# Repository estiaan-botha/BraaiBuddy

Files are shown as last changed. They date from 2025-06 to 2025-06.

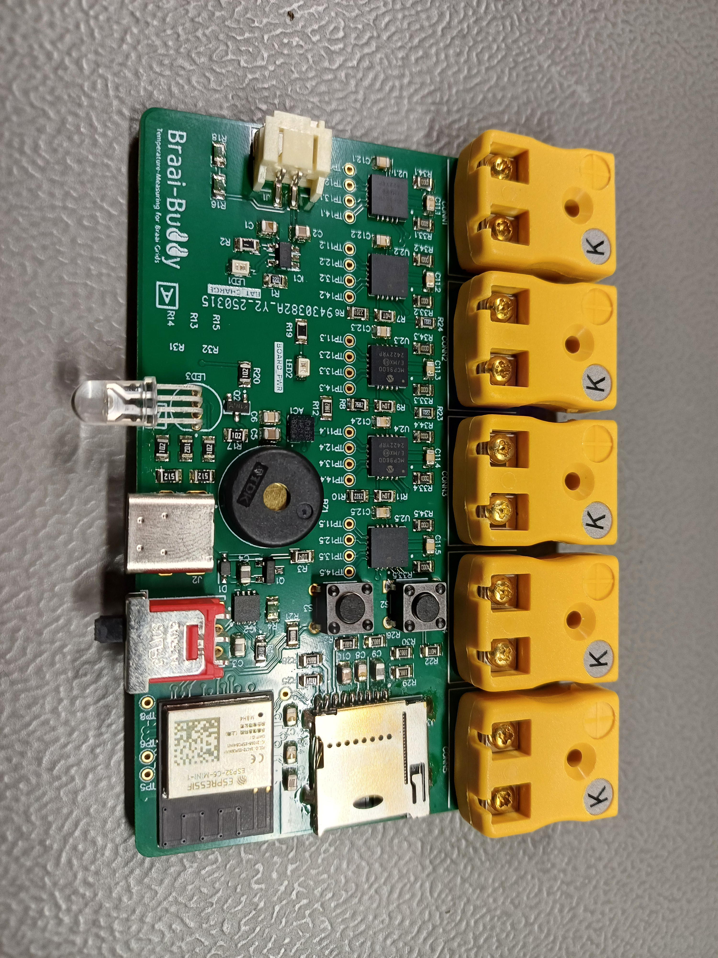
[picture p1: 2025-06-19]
Pictures/real_pcb_photo_2.jpg

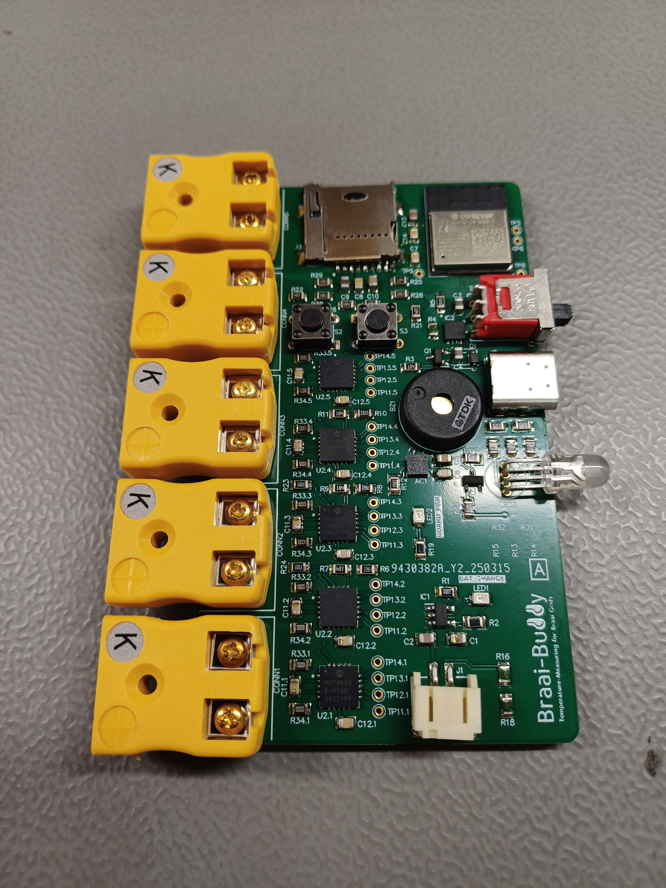
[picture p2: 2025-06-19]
Pictures/real_pcb_photo.jpg

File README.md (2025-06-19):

# BraaiBuddy
BraaiBuddy: Smart Monitoring and Notification System for use in a braai cooking environment.

This repository is for the personal continuation of my final year E&E Engineering project, in which I designed and built a smart device that monitors the internal temperatures of meat and the surface-level cooking temperatures while braaiing. The system can connect with a smart device where real-time temperature information is displayed, and preset selections can be made for the type of meat and the desired level of doneness.

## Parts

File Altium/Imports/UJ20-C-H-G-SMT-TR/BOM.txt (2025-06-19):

3DX_Same_Sky_Supplier: Same Sky
3DX_Same_Sky_Description: Type C, USB 2.0, 480 Mbps, 20 Vdc, 5 A, Right Angle, Gold Flash, Surface Mount, Black Insulator, USB Receptacle
3DX_Same_Sky_Model Number: UJ20-C-H-G-SMT-TR

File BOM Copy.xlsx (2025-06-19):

LibRef | Designator | Quantity | Manufacturer_Part_Number
IC ACC MEMS 3-AXIS 11uA SMD | AC1 | 1 | LIS3DHTR
INDICATOR BUZZER PIEZO PS1240P02CT3 | BZ1 | 1 | PS1240P02CT3
CAP CER 10uF 0805 SMD | C1, C2, C5, C10, C13 | 5 | CL21A106KOQNNNE
CAP CER 2u2F 0805 SMD | C3, C4, C9 | 3 | LMK212BJ225MG-T
CAP CER 100nF 0805 SMD | C6, C7, C8, C11.1, C11.2, C11.3, C11.4, C11.5, C12.1, C12.2, C12.3, C12.4, C12.5, C14 | 14 | 08055C104KAZ2A
CONN AM-K-PCB XE-1139-001 | CONN1, CONN2, CONN3, CONN4, CONN5 | 5 | XE-1139-001
DIODE SCHOTTKY 1A 23V 620mV SMD | D1 | 1 | BAT20JFILM
IC BATT CHG MGNT Li-Po 4V2 REG SMD | IC1 | 1 | MCP73831T-2ACI/OT
IC LDO 1A 5V5 ADJ SMD SON-8 | IC2 | 1 | TPS78501QWDRBRQ1
I/O JST-PH 2-PIN SMT | J1 | 1 | 1769
CONN USB-C 2.0 16 CONTACT 5A 42V SMD | J2 | 1 | UJ20-C-H-G-MSMT-2-P16-TR
SD CARD SOCKET SMD MEM2075-00-140-01-A | J3 | 1 | MEM2075-00-140-01-A
LED YELLOW 0805 SMD | LED1, LED2 | 2 | LY M676-Q2S1-26-Z
LED RGB THP SRAIGHT-LEG | LED3 | 1 | 521-8559F
MOSFET P-CH ENH FET -20V 52mOh -5A SMD | Q1 | 1 | DMG2305UX-7
BJT NPN 3904 SMD SOT-23 | Q2 | 1 | MMBT3904
RES 2.2K 0805 SMD | R1, R23, R24 | 3 | ERJ-PB6B2201V
RES 4.7K 0805 SMD | R2, R19 | 2 | CRCW08054K70FKEA
RES 100K 0805 SMD | R3, R7, R9, R11, R21, R22, R25 | 7 | CRCW0805100KJNECC
RES 200K 0805 SMD | R4, R16, R18 | 3 | SG73P2ATTD2003F
RES 357K 0805 SMD | R5 | 1 | ERJ-6ENF3573V
RES 220K 0805 SMD | R6 | 1 | CR0805-FX-2203ELF
RES 76.8K 0805 SMD | R8 | 1 | RC0805FR-0776K8L
RES 23.2K 0805 SMD | R10 | 1 | RC0805FR-0723K2L
RES 10K 0805 SMD | R12, R26, R27, R28, R29, R30 | 6 | CR0805-FX-1002ELF
RES 1K 0805 SMD | R13, R14, R15, R17, R20 | 5 | RC0805JR-071KL
RES 5.1K 0805 SMD | R31, R32 | 2 | RC0805JR-075K1L
RES 100 0805 SMD | R33.1, R33.2, R33.3, R33.4, R33.5, R34.1, R34.2, R34.3, R34.4, R34.5 | 10 | 1623096-1
SWITCH SPDT 3A 120V | S1 | 1 | 500ASSP1M6QE
BUTT PUSH N/O SPST THP 50mA | S2, S3 | 2 | TS02-66-43-BK-100-LCR-D
ESP32-C6-MINI-1 | U1 | 1 | ESP32-C6-MINI-1-H8
IC TYPE_K AMP I2Q MCP9600-I/MX SMD | U2.1, U2.2, U2.3, U2.4, U2.5 | 5 | MCP9600-E/MX
 |  | 91

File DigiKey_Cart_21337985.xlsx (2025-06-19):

Index | Quantity | Part Number | Manufacturer Part Number | Description | Customer Reference | Available | Backorder | Unit Price | Extended Price ZAR
1 | 5 | 5425-XE-1384-001-ND | XE-1384-001 | BS MINI TYPE K PLUG BM-K-M |  | 5 | 0 | 74.436 | ZAR372,18
2 | 5 | 1778-COM1706-ND | COM1706 | TYPE-K SS STL THERMOCOUPLE |  | 5 | 0 | 108.38 | ZAR541,90
3 | 2 | 497-10613-1-ND | LIS3DHTR | ACCEL 2-16G I2C/SPI 16LGA |  | 2 | 0 | 27.37 | ZAR54,74
4 | 2 | 445-5229-1-ND | PS1240P02CT3 | BUZZER PIEZO 3V 12.2MM TH |  | 2 | 0 | 11.02 | ZAR22,04
5 | 10 | 587-5919-1-ND | LMK212BJ225MG-T | CAP CER 2.2UF 10V X5R 0805 |  | 10 | 0 | 2.021 | ZAR20,21
6 | 10 | 1276-1096-1-ND | CL21A106KOQNNNE | CAP CER 10UF 16V X5R 0805 |  | 10 | 0 | 0.625 | ZAR6,25
7 | 28 | 478-KGF21BR71H104KTCT-ND | 08055C104KAZ2A | CAP CER 0.1UF 50V X7R 0805 |  | 28 | 0 | 2.921 | ZAR81,79
8 | 5 | 5425-XE-1139-001-ND | XE-1139-001 | ANSI TYPE K PCB SOCKET AM-K-PCB |  | 5 | 0 | 74.436 | ZAR372,18
9 | 5 | 497-3381-1-ND | BAT20JFILM | DIODE SCHOTTKY 23V 1A SOD323 |  | 5 | 0 | 4.96 | ZAR24,80
10 | 3 | MCP73831T-2ACI/OTCT-ND | MCP73831T-2ACI/OT | IC BATT CNTL LI-ION 1CEL SOT23-5 |  | 3 | 0 | 13.96 | ZAR41,88
11 | 3 | 296-TPS78501QWDRBRQ1CT-ND | TPS78501QWDRBRQ1 | IC REG LINEAR POS ADJ 1A 8-SON |  | 3 | 0 | 27.19 | ZAR81,57
12 | 2 | 2073-MEM2075-00-140-01-ACT-ND | MEM2075-00-140-01-A | CONN MICRO SD CARD R/A SMD |  | 2 | 0 | 34.17 | ZAR68,34
13 | 3 | 350-5218559F-ND | 5218559F | LED RGB CLEAR 5MM T/H |  | 3 | 0 | 15.8 | ZAR47,40
14 | 5 | DMG2305UX-7DICT-ND | DMG2305UX-7 | MOSFET P-CH 20V 4.2A SOT23 |  | 5 | 0 | 3.86 | ZAR19,30
15 | 10 | P20630CT-ND | ERJ-PB6B2201V | RES SMD 2.2K OHM 0.1% 1/4W 0805 |  | 10 | 0 | 2.498 | ZAR24,98
16 | 10 | 541-4.70KCCT-ND | CRCW08054K70FKEA | RES SMD 4.7K OHM 1% 1/8W 0805 |  | 10 | 0 | 0.772 | ZAR7,72
17 | 20 | 118-CR0805-JW-104ELFCT-ND | CR0805-JW-104ELF | RES SMD 100K OHM 5% 1/8W 0805 |  | 20 | 0 | 0.423 | ZAR8,46
18 | 10 | 2019-SG73P2ATTD2003FCT-ND | SG73P2ATTD2003F | RES 200K OHM 1% 1/2W 0805 |  | 10 | 0 | 1.176 | ZAR11,76
19 | 10 | P357KCCT-ND | ERJ-6ENF3573V | RES SMD 357K OHM 1% 1/8W 0805 |  | 10 | 0 | 0.974 | ZAR9,74
20 | 10 | CR0805-FX-2203ELFCT-ND | CR0805-FX-2203ELF | RES SMD 220K OHM 1% 1/8W 0805 |  | 10 | 0 | 0.514 | ZAR5,14
21 | 10 | 311-76.8KCRCT-ND | RC0805FR-0776K8L | RES 76.8K OHM 1% 1/8W 0805 |  | 10 | 0 | 0.22 | ZAR2,20
22 | 10 | 311-23.2KCRCT-ND | RC0805FR-0723K2L | RES 23.2K OHM 1% 1/8W 0805 |  | 10 | 0 | 0.202 | ZAR2,02
23 | 20 | CR0805-FX-1002ELFCT-ND | CR0805-FX-1002ELF | RES SMD 10K OHM 1% 1/8W 0805 |  | 20 | 0 | 0.478 | ZAR9,56
24 | 10 | 311-1.0KARCT-ND | RC0805JR-071KL | RES 1K OHM 5% 1/8W 0805 |  | 10 | 0 | 0.22 | ZAR2,20
25 | 20 | A106053CT-ND | CRG0805F100R | RES SMD 100 OHM 1% 1/8W 0805 |  | 20 | 0 | 0.643 | ZAR12,86
26 | 1 | EG2483-ND | 500ASSP1M6QE | SWITCH SLIDE SPDT 3A 120V |  | 1 | 0 | 99.75 | ZAR99,75
27 | 4 | 2223-TS02-66-43-BK-100-LCR-D-ND | TS02-66-43-BK-100-LCR-D | SWITCH TACTILE SPST-NO 0.05A 12V |  | 4 | 0 | 1.84 | ZAR7,36
28 | 6 | MCP9600-E/MX-ND | MCP9600-E/MX | IC THERMOCOUPLE TO I2C 20MQFN |  | 6 | 0 | 161.47 | ZAR968,82
29 | 5 | MMBT3904-FDICT-ND | MMBT3904-7-F | TRANS NPN 40V 0.2A SOT-23-3 |  | 5 | 0 | 2.2 | ZAR11,00
30 | 10 | 311-5.1KARCT-ND | RC0805JR-075K1L | RES 5.1K OHM 5% 1/8W 0805 |  | 10 | 0 | 0.147 | ZAR1,47
31 | 2 | 455-S2B-PH-SM4-TBCT-ND | S2B-PH-SM4-TB | CONN HEADER SMD R/A 2POS 2MM |  | 2 | 0 | 9.37 | ZAR18,74
32 | 4 | 475-LYM676-Q2T1-26-ZCT-ND | LY M676-Q2T1-26-0-20-R18-Z | LED YELLOW CLEAR 2SMD |  | 4 | 0 | 6.43 | ZAR25,72
33 | 4 | 2223-UJ20-C-H-G-SMT-TRCT-ND | UJ20-C-H-G-SMT-TR | TYPE C, USB 2.0, 480 MBPS, 20 VA |  | 4 | 0 | 19.29 | ZAR77,16
34 | 2 | 1965-ESP32-C6-MINI-1-H4CT-ND | ESP32-C6-MINI-1-H4 | RF TXRX MODULE BT PCB TRACE SMD |  | 2 | 0 | 82.85 | ZAR165,70

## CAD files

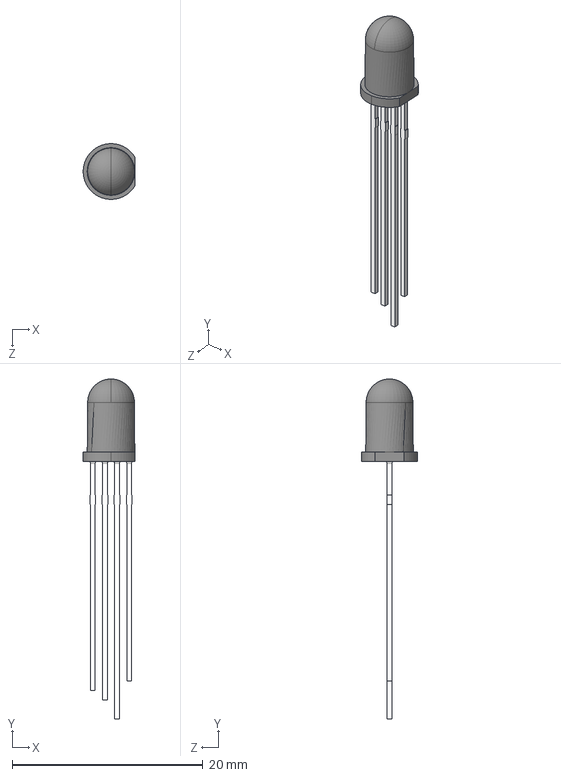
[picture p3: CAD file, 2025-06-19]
Altium/Imports/HV-5RGB25/3D/HV-5RGB25.stp
5.42 x 35.6 x 5.85 mm

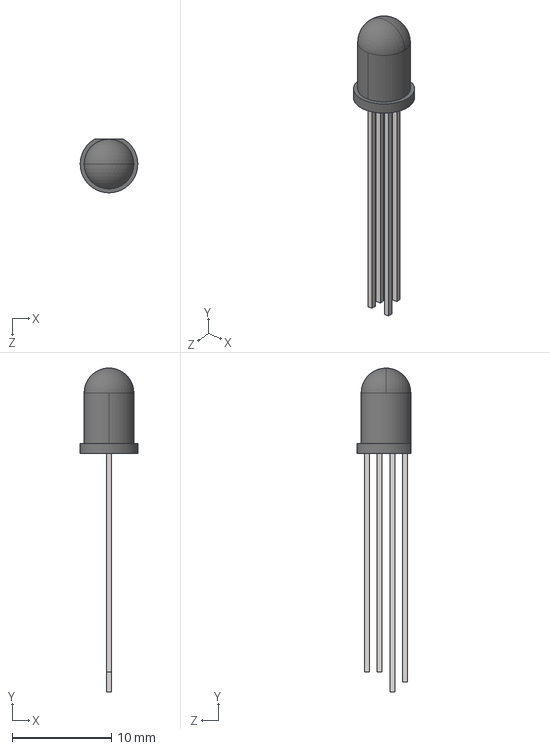
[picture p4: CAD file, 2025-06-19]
Altium/Imports/LIB_521-8559F/521-8559F/3D/521-8559F.stp
5.79 x 32.6 x 5.40 mm

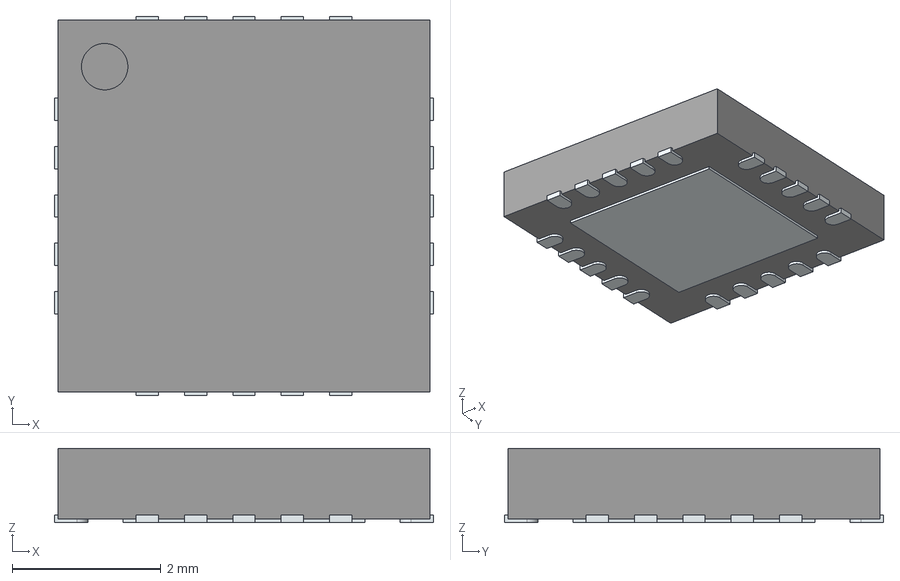
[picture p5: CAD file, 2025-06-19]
Altium/Imports/LIB_MCP9600-E_MX/MCP9600-E_MX/3D/MCP9600-E_MX.stp
5.10 x 5.10 x 1.00 mm
ThermalPin
PinsArrayLR
PinsArrayTB

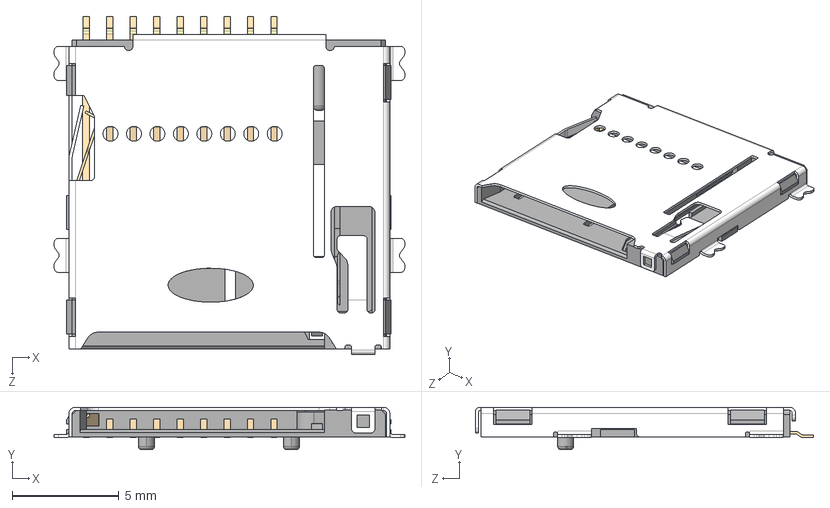
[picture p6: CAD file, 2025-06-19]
Altium/Imports/LIB_MEM2075-00-140-01-A/MEM2075-00-140-01-A/3D/MEM2075-00-140-01-A.stp
16.4 x 1.99 x 15.9 mm
MEM2075-00-140-01-A
MEM2075-00-140-01-A_1
MEM2075-00-140-01-A_2

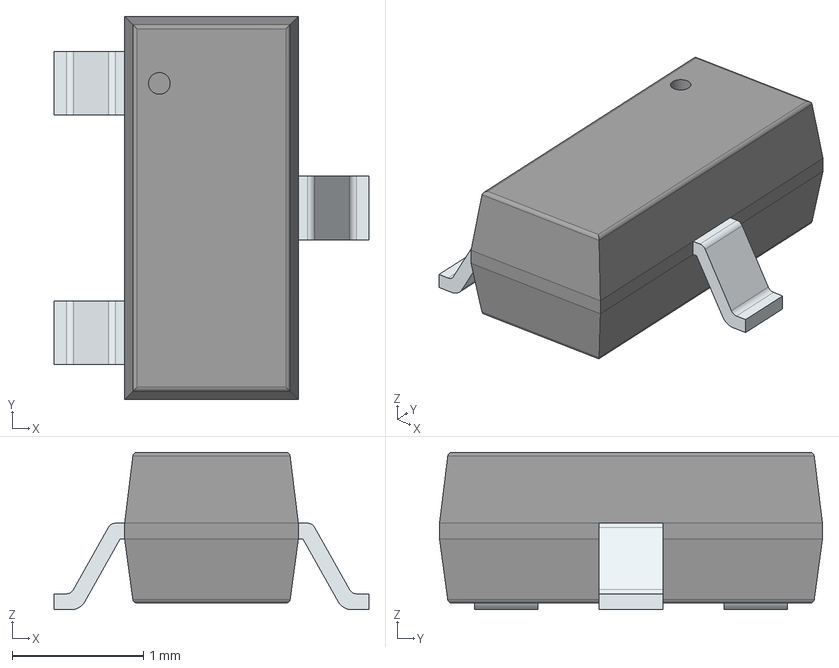
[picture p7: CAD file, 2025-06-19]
Altium/Imports/MMBT3904.stp
2.40 x 2.92 x 1.20 mm
PinsArrayL
FilletPinR

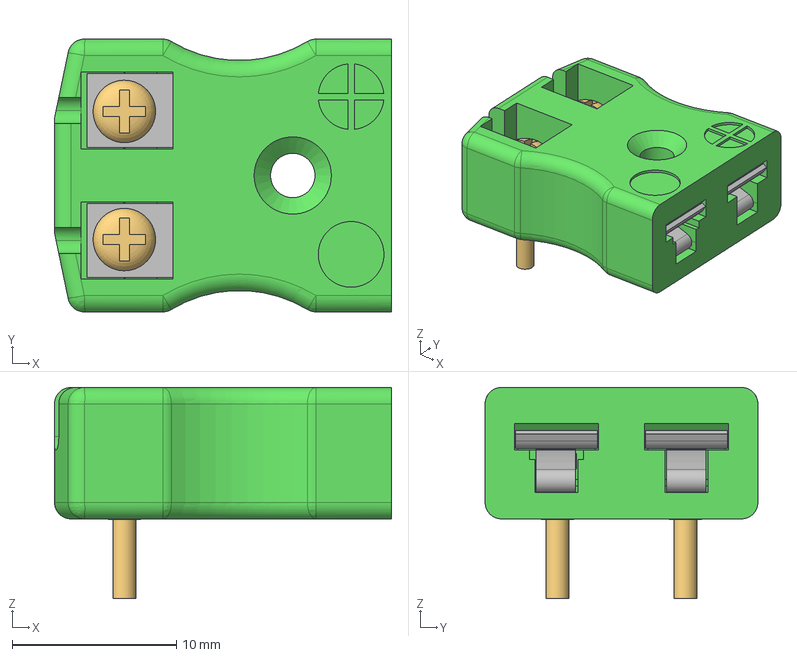
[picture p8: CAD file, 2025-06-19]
Altium/Imports/pcb-socket-for-type-k-thermocouple-1.snapshot.7/IM-K-PCB.step
20.5 x 16.6 x 12.9 mm
BottomBlade x 2
Screw x 2
M2-Écrou x 2
TopBlade x 2

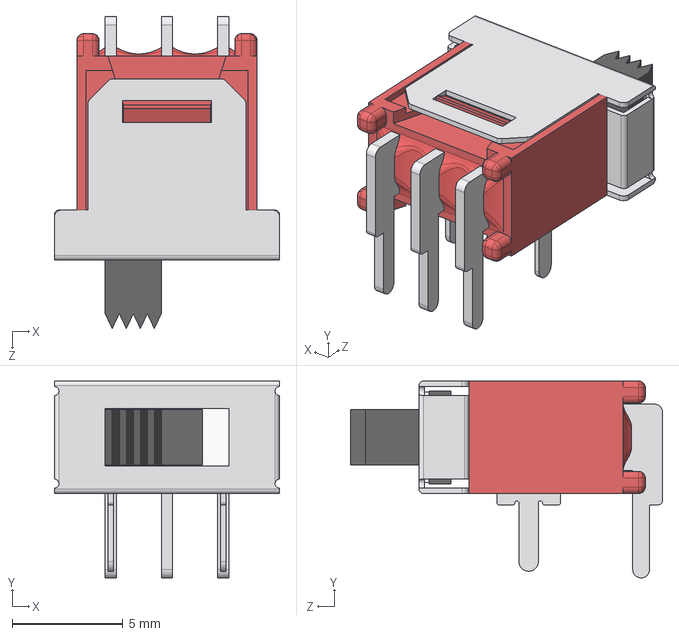
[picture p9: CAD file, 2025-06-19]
Altium/Imports/500ASSP1M6QE.step
10.2 x 8.89 x 14.1 mm

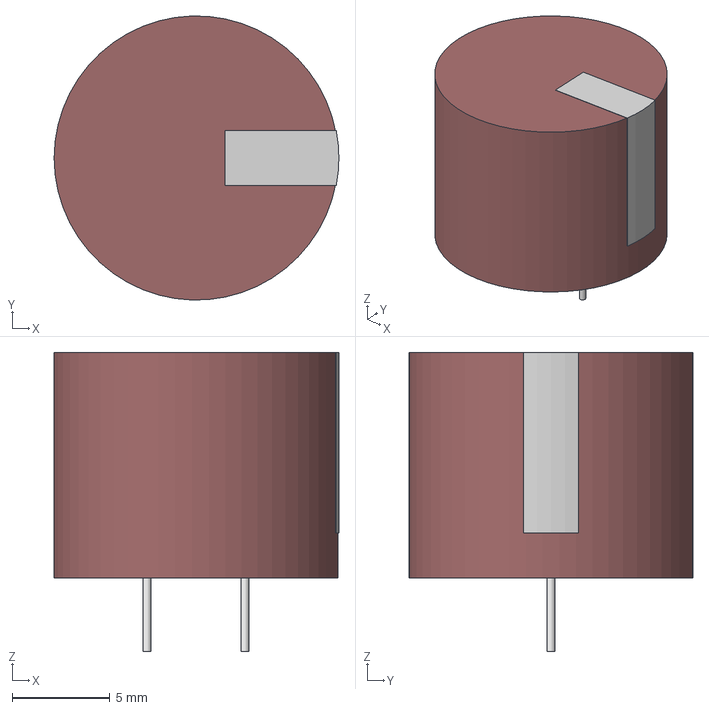
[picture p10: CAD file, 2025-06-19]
Altium/Imports/SMT_PP02CT3_TDK.step
14.5 x 14.5 x 15.3 mm

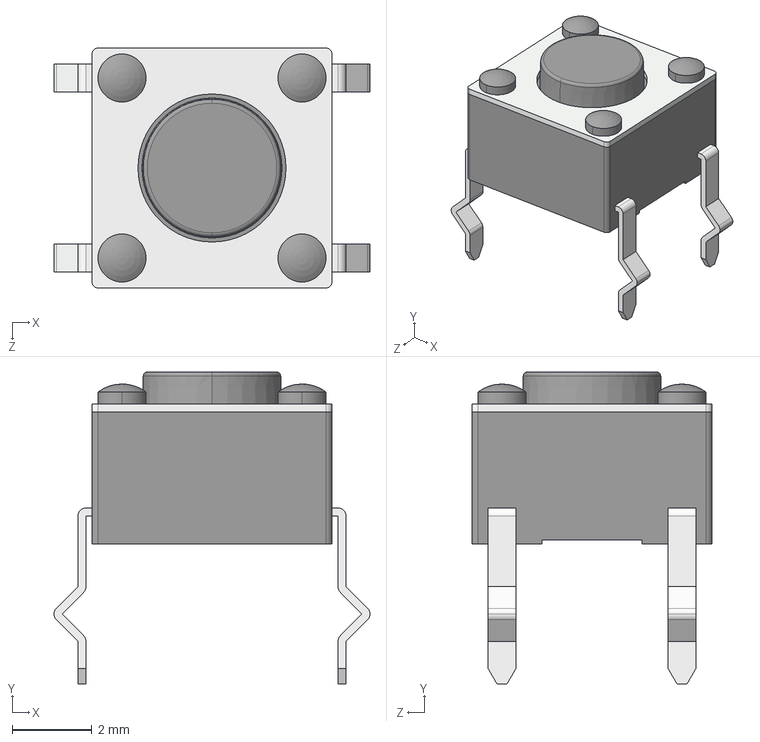
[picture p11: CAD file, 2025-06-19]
Altium/Imports/TS02-66-43-BK-100-LCR-D.step
7.90 x 7.80 x 6.00 mm

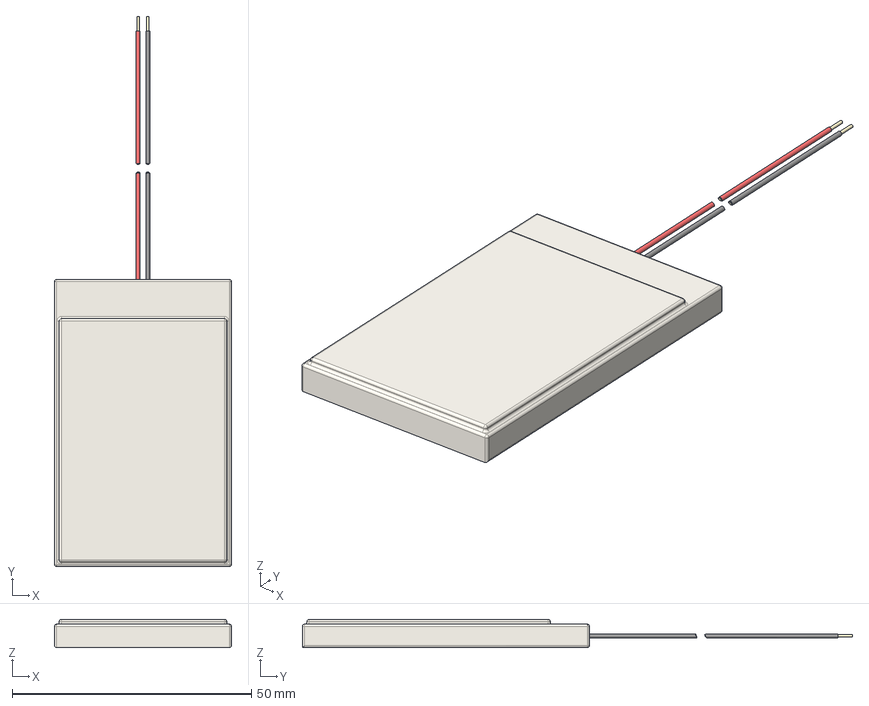
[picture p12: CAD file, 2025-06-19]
Altium/Imports/LIB_ICP543759PMT/ICP543759PMT/3D/ICP543759PMT.stp
37.0 x 115.0 x 5.90 mm

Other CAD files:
Altium/Imports/pcb-socket-for-type-k-thermocouple-1.snapshot.7/AM-K-PCB.step
Altium/Imports/HV-5RGB25/Allegro/hv5rgb25.psm
Altium/Imports/HV-5RGB25/DEHDL/hv_5rgb25/chips/chips.prt
Altium/Imports/LIB_521-8559F/521-8559F/Allegro/5218559f.psm
Altium/Imports/LIB_521-8559F/521-8559F/DEHDL/521_8559f/chips/chips.prt
Altium/Imports/LIB_MCP9600-E_MX/MCP9600-E_MX/Allegro/qfn65p500x500x100-21n-d.psm
Altium/Imports/LIB_MCP9600-E_MX/MCP9600-E_MX/DEHDL/mcp9600_e_mx/chips/chips.prt
Altium/Imports/LIB_MEM2075-00-140-01-A/MEM2075-00-140-01-A/Allegro/mem20750014001a.psm
Altium/Imports/LIB_MEM2075-00-140-01-A/MEM2075-00-140-01-A/DEHDL/mem2075_00_140_01_a/chips/chips.prt
Altium/Imports/UJ20-C-H-G-SMT-TR/Same_Sky_UJ20-C-H-G-SMT-TR.x_t

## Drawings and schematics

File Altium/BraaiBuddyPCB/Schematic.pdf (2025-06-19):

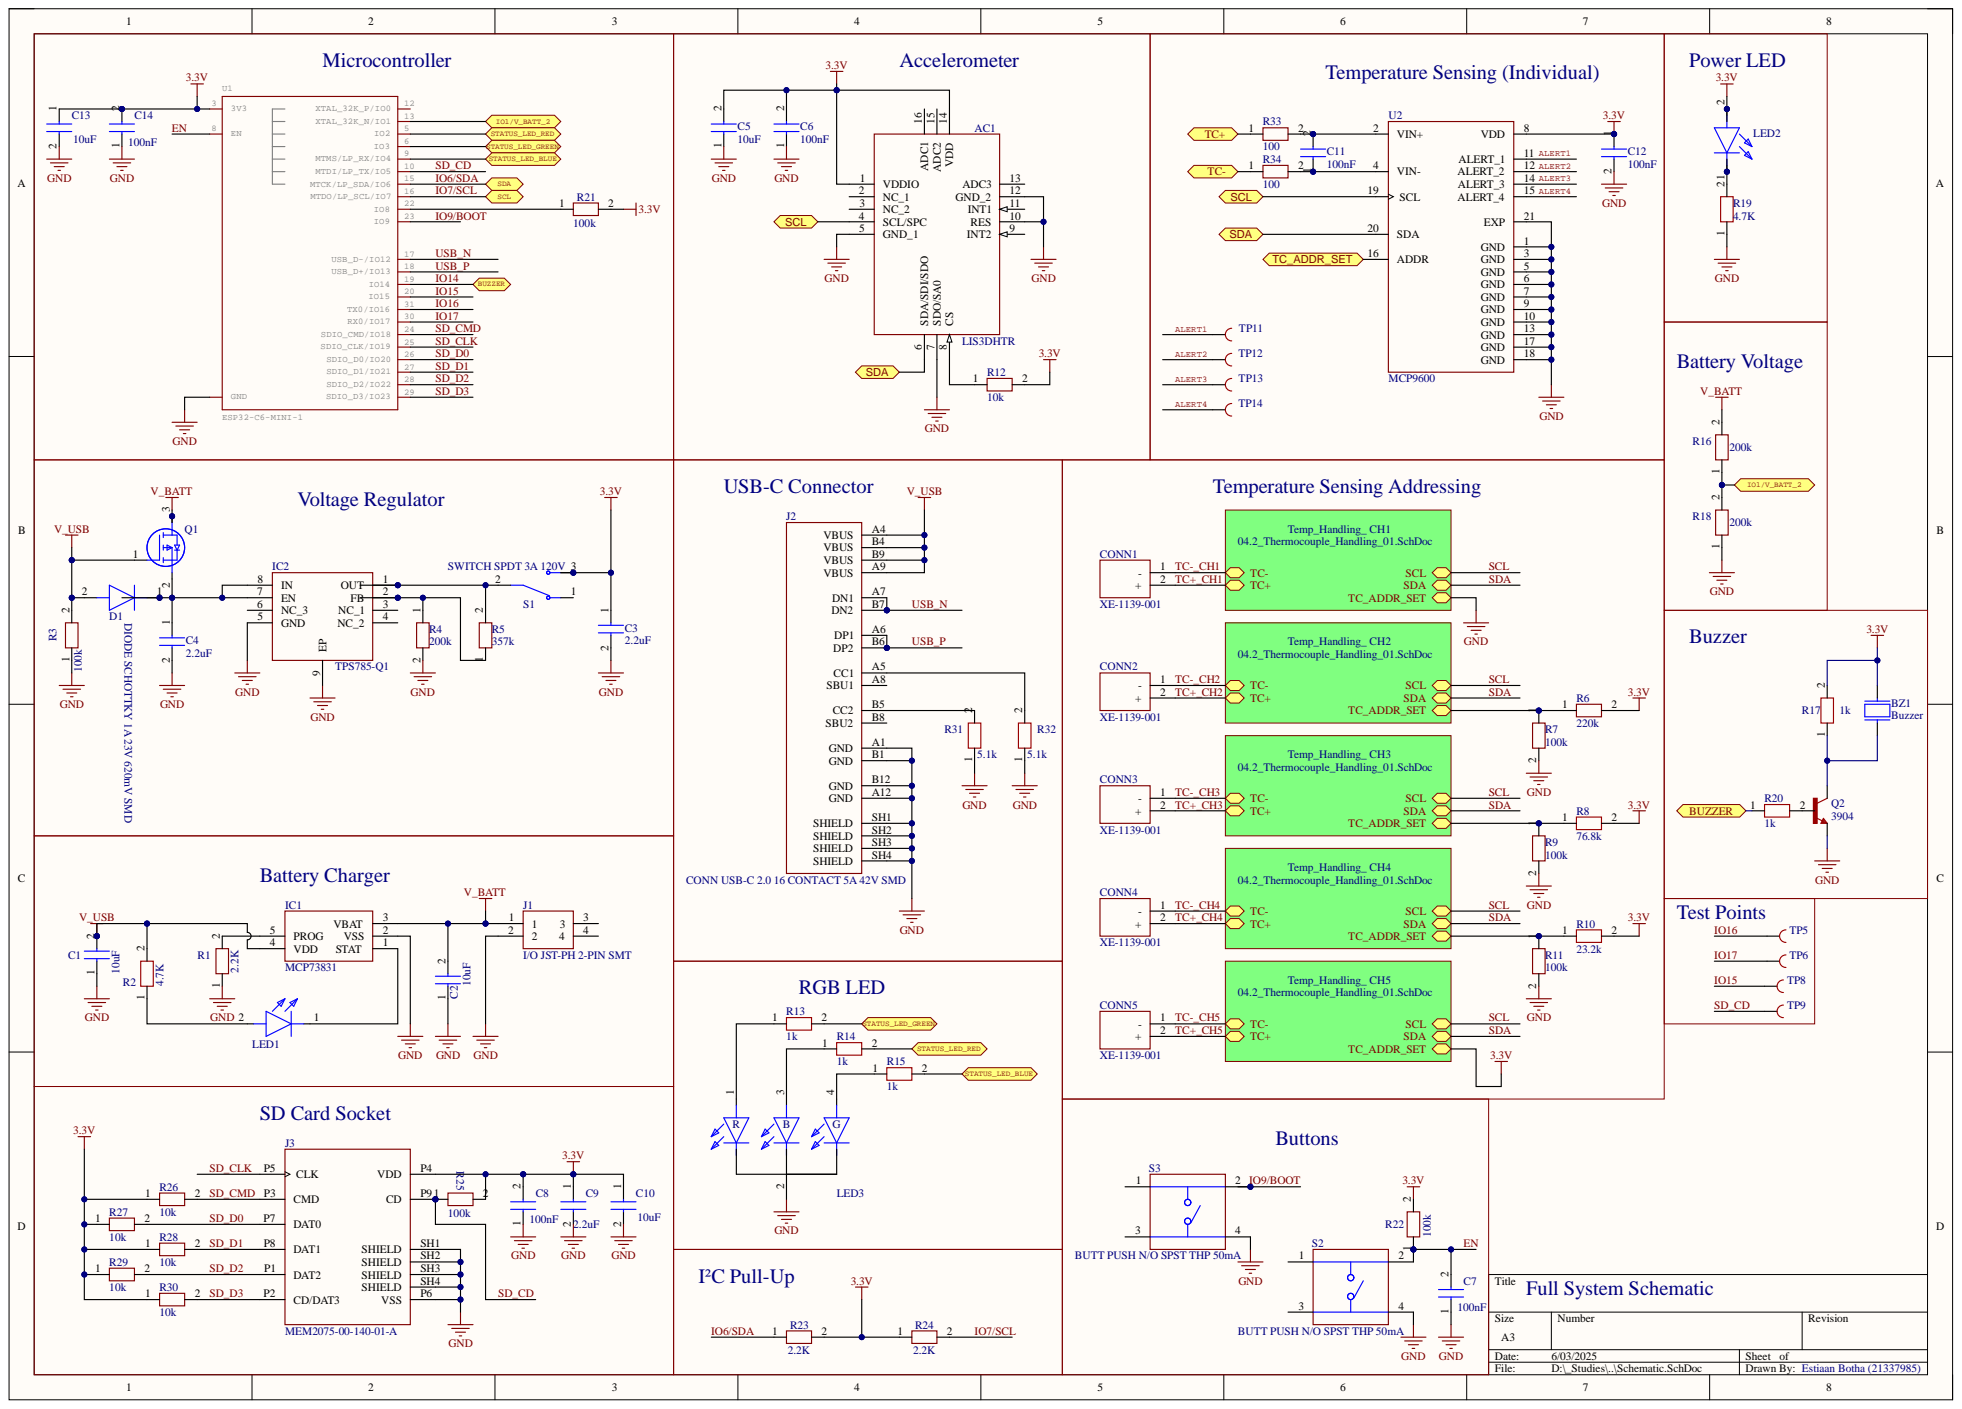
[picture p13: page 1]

CONN USB-C 2.0 16 CONTACT 5A 42V SMD

I/O JST-PH 2-PIN SMT

BUTT PUSH N/O SPST THP 50mA

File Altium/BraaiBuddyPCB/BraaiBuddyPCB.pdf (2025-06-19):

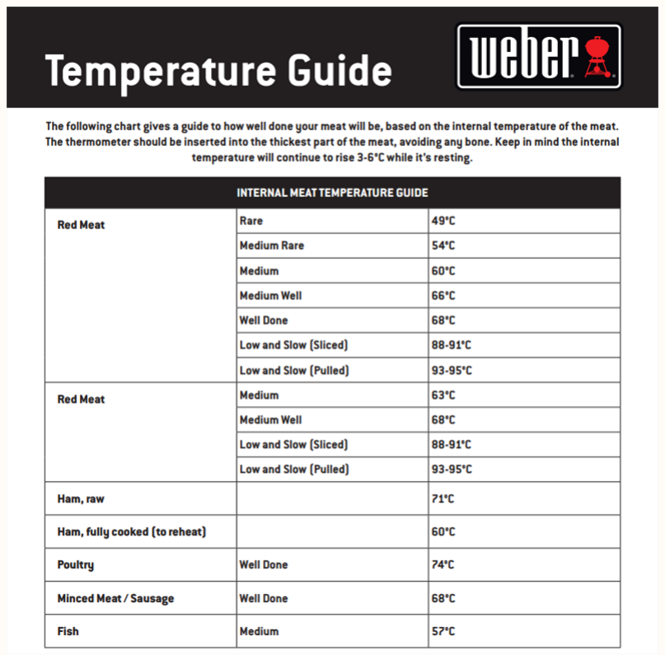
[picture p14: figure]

A | A

+3V6

Power Management

02_Power.SchDoc

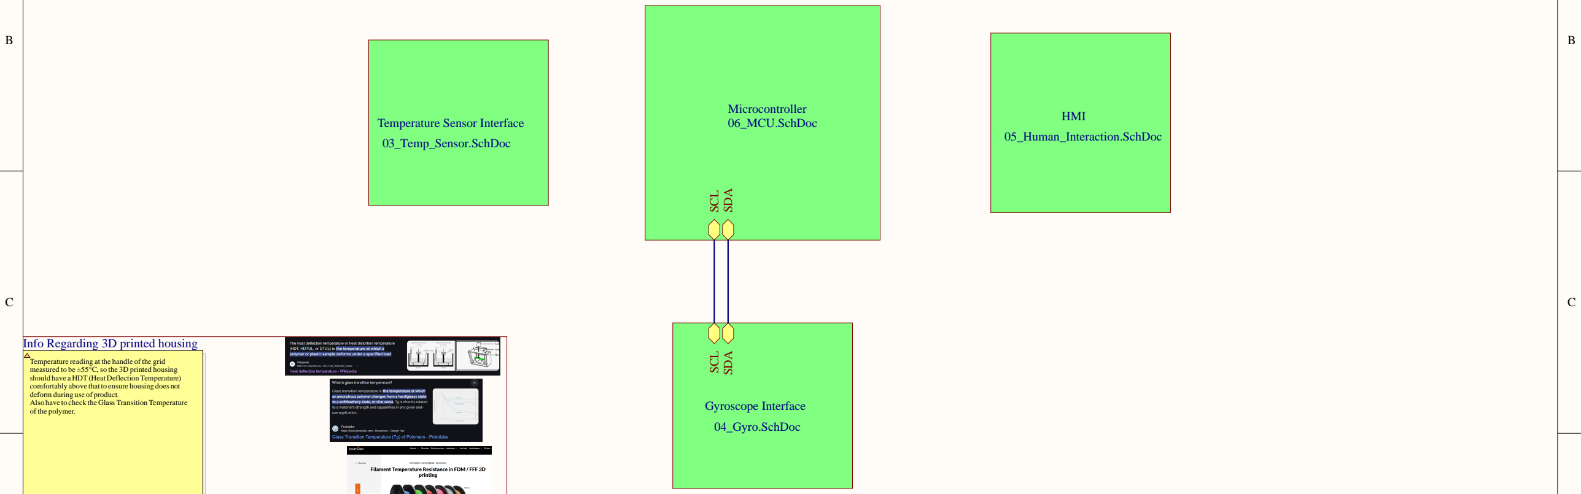
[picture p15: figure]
SCL; SDA Microcontroller; Temperature Sensor Interface; 06_MCU.SchDoc; 03_Temp_Sensor.SchDoc; SDA; Gyroscope Interface; 04_Gyro.SchDoc; HMI; 05_Human_Interaction.SchDoc; Info Regarding 3D printed housing; deform during use of product.; of the polymer.
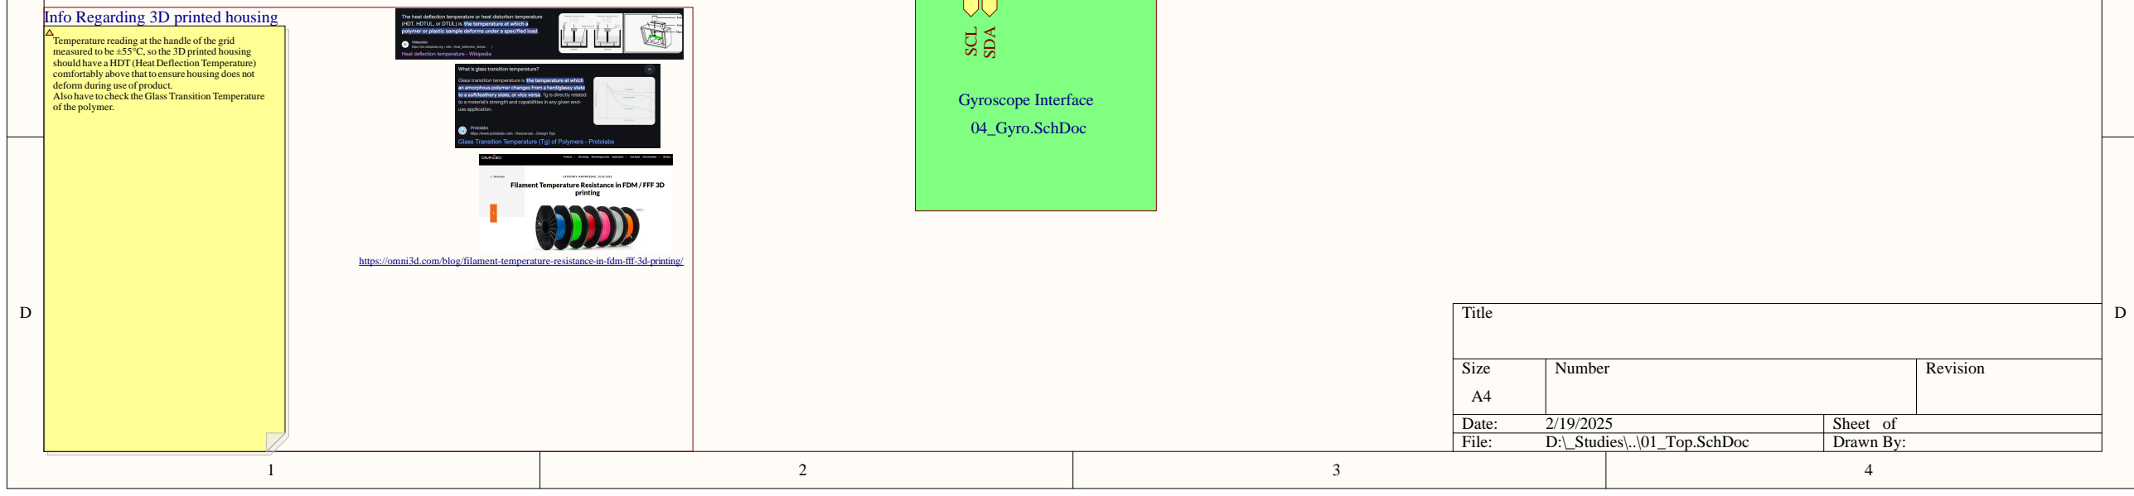
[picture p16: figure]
Title; Size; Number; Revision; Date:; Sheet of; File:; D:\_Studies\..\01_Top.SchDoc; Drawn By:; https://omni3d.com/blog/filament-temperature-resistance-in-fdm-fff-3d-printing/

Temperature reading at the handle of the grid measured to be ±55°C, so the 3D printed housing should have a HDT(Heat Deflection Temperature) comfortably above that to ensure housing does not

Also have to check the Glass Transition Temperature

Product Specifications:
Battery Life: 2 hours

Temperature sensing range (max): 400°C (or roughly 350°C)

Module operating temperature range: roughly 60°C ambient on outside of module. With heat insulation in place, hopefully reduce ambient temperature to a max of 40°C (possibly lower)

Sensing accuracy (max): ±2°C (since meat has a 5°C range between doneness levels)

Interaction: rocker power switch, LEDs to indicate when grill needs to be turned, connect to mobile through WiFi and display GUI, run HTML web app with arelevant information and selection of presets

Gyro: to sense when the grid has been flipped

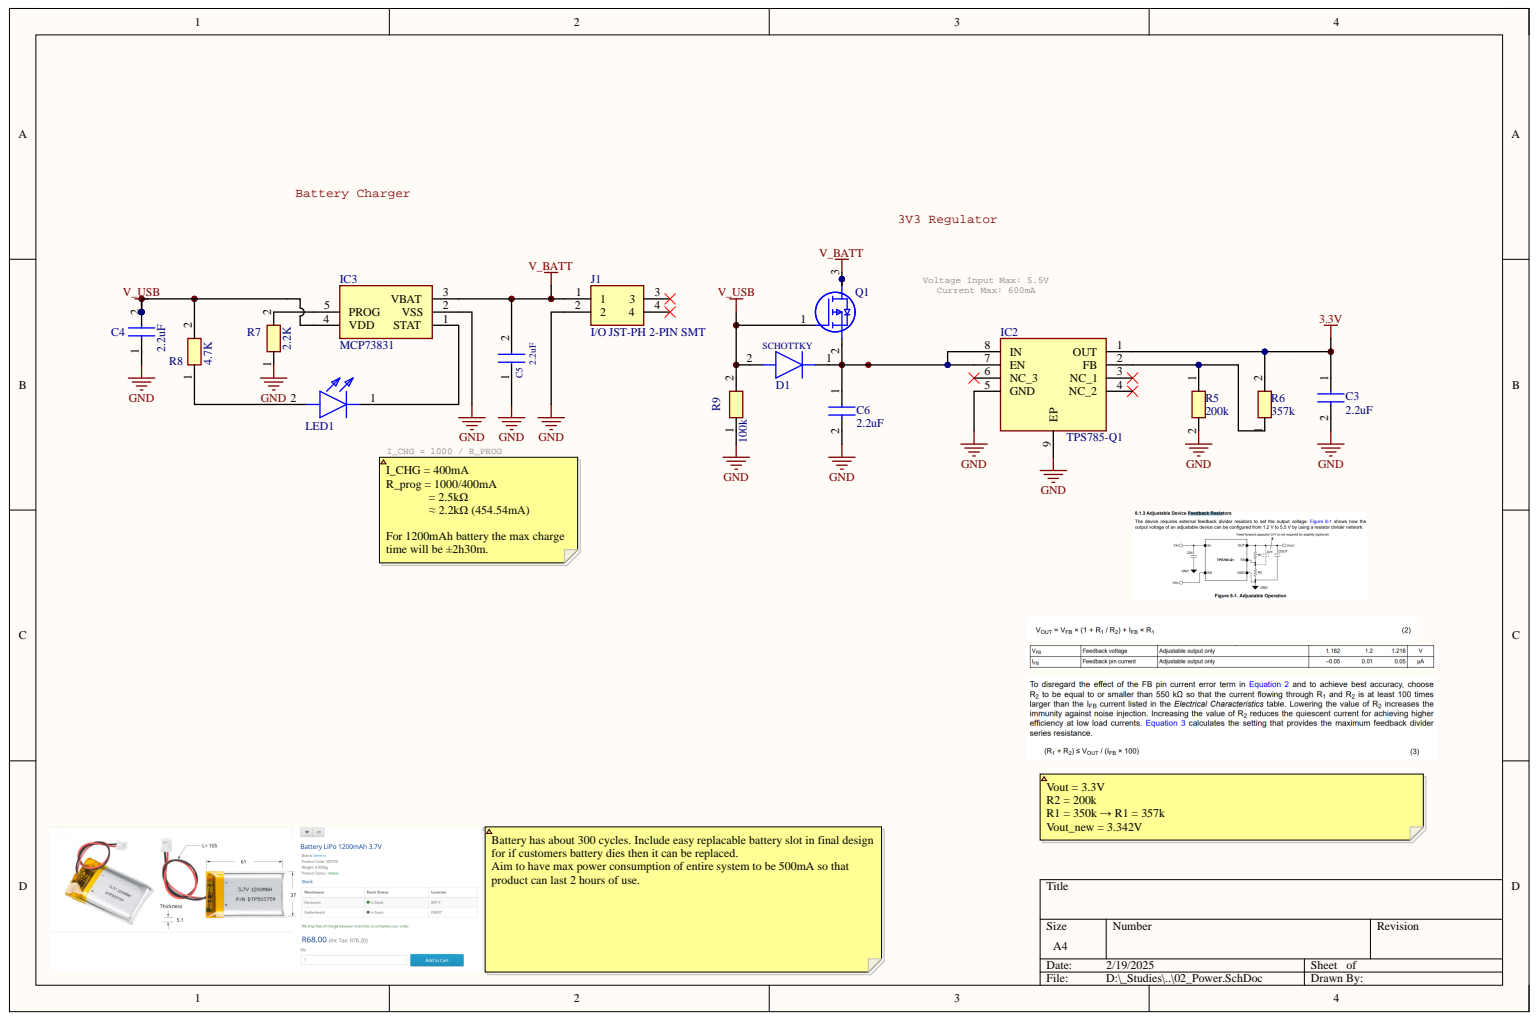
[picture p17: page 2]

For 1200mAh battery the max charge
time will be

Battery has about 300 cycles. Include easy replacable battery slot in final design
for if customers battery dies then it can be replaced.
Aim to have max power consumption of entire system to be 500mA so that
product can last 2 hours of use.

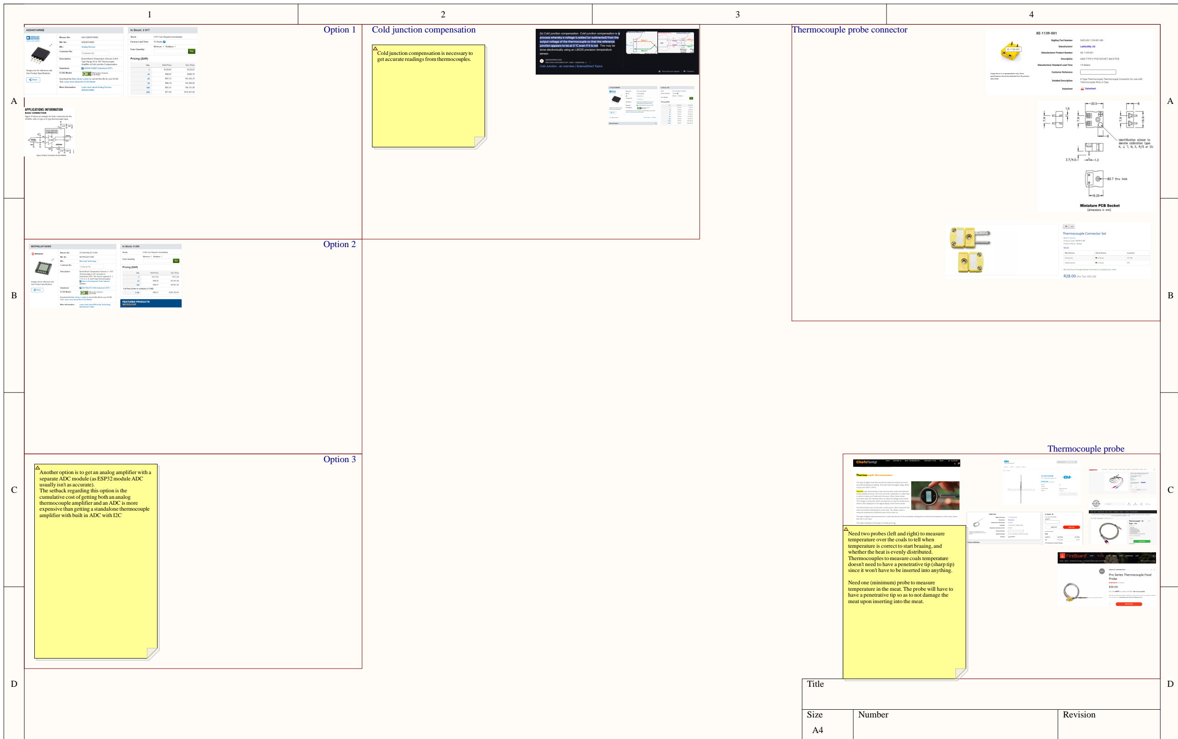
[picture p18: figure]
Title; Size; Number; Revision; Option 1; Option 2; Thermocouple probe connector; Thermocouple probe; Cold junction compensation; Option 3; temperature over the coals to tell when; whether the heat is evenly distributed. Thermocouples to measure coals temperature; Need one (minimum) probe to measure; meat upon inserting into the meat.; get accurate readings from thermocouples.; usually isn't as accurate).; amplifier with built in ADC with I2C
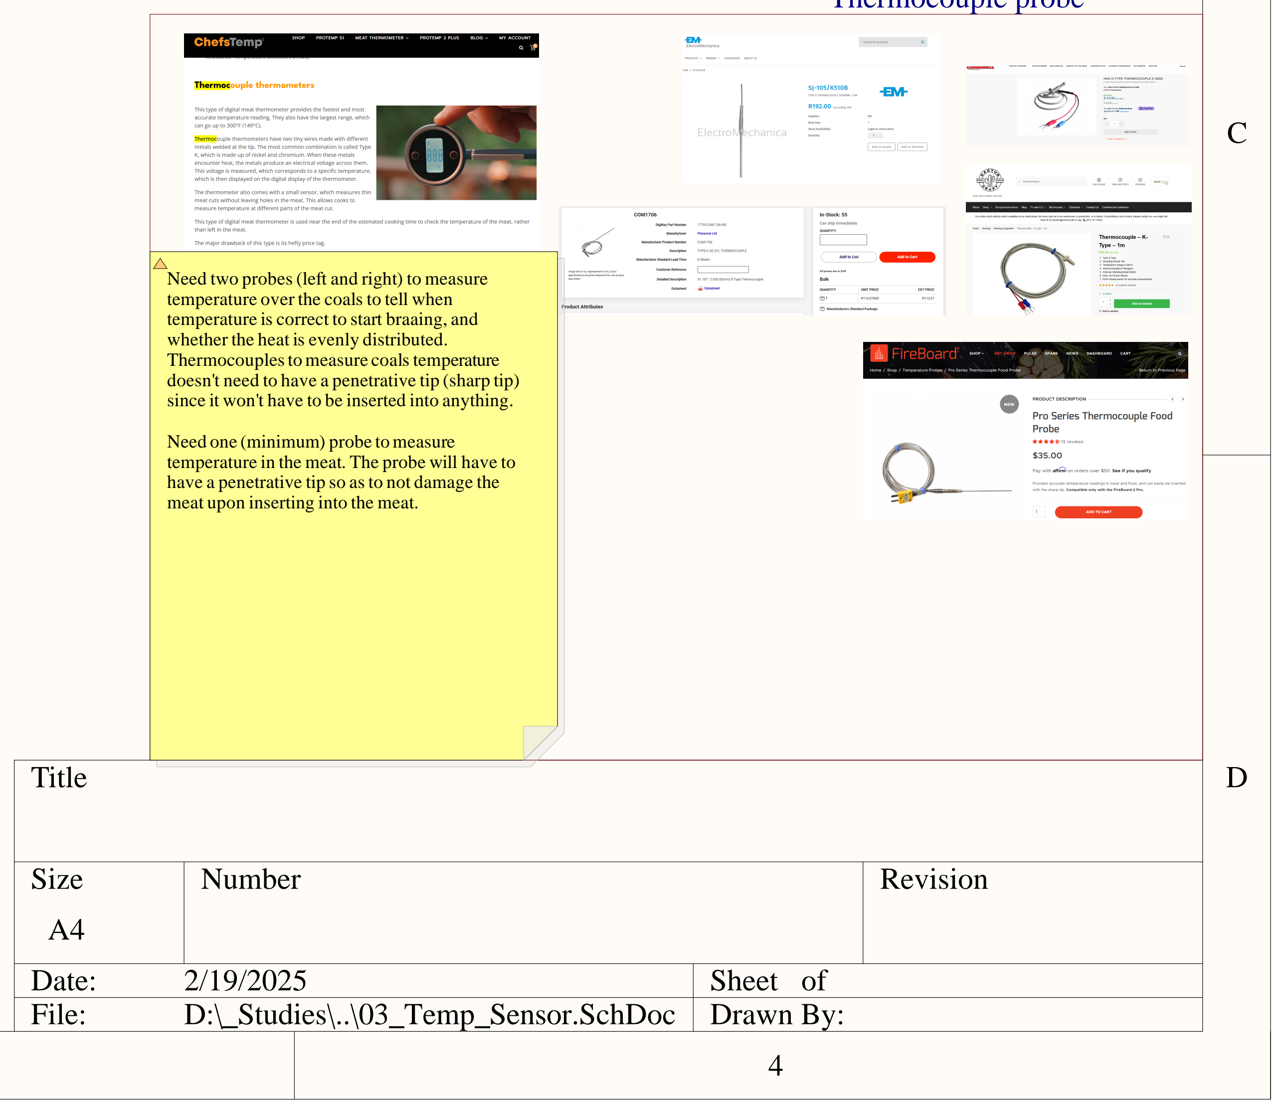
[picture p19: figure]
File:; D:\_Studies\..\03_Temp_Sensor.SchDoc; Drawn By:

Need two probes (left and right) to measure

temperature is correct to start braaing, and

doesn't need to have a penetrative tip (sharp tip) since it won't have to be inserted into anything.

temperature in the meat. The probe will have to have a penetrative tip so as to not damage the

Cold junction compensation is necessary to

Another option is to get an analog amplifier with a separate ADC module (as ESP32 module ADC

The setback regarding this option is the cumulative cost of getting both an analog thermocouple amplifier and an ADC is more expensive than getting a standalone thermocouple

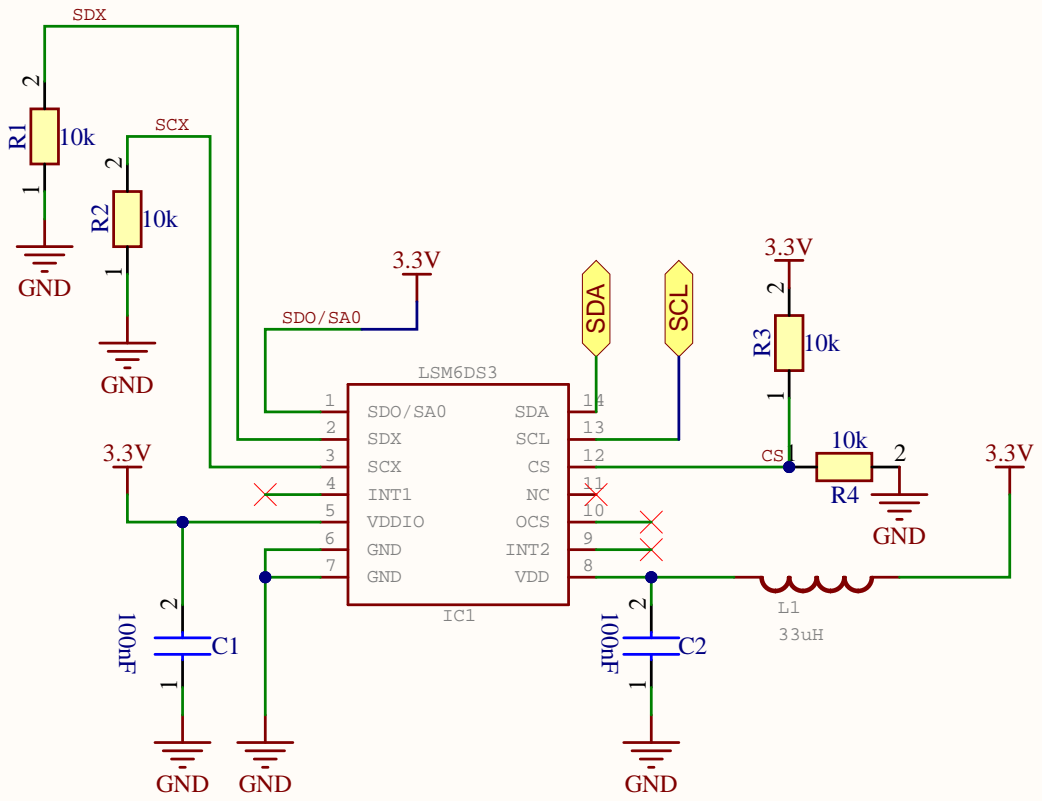
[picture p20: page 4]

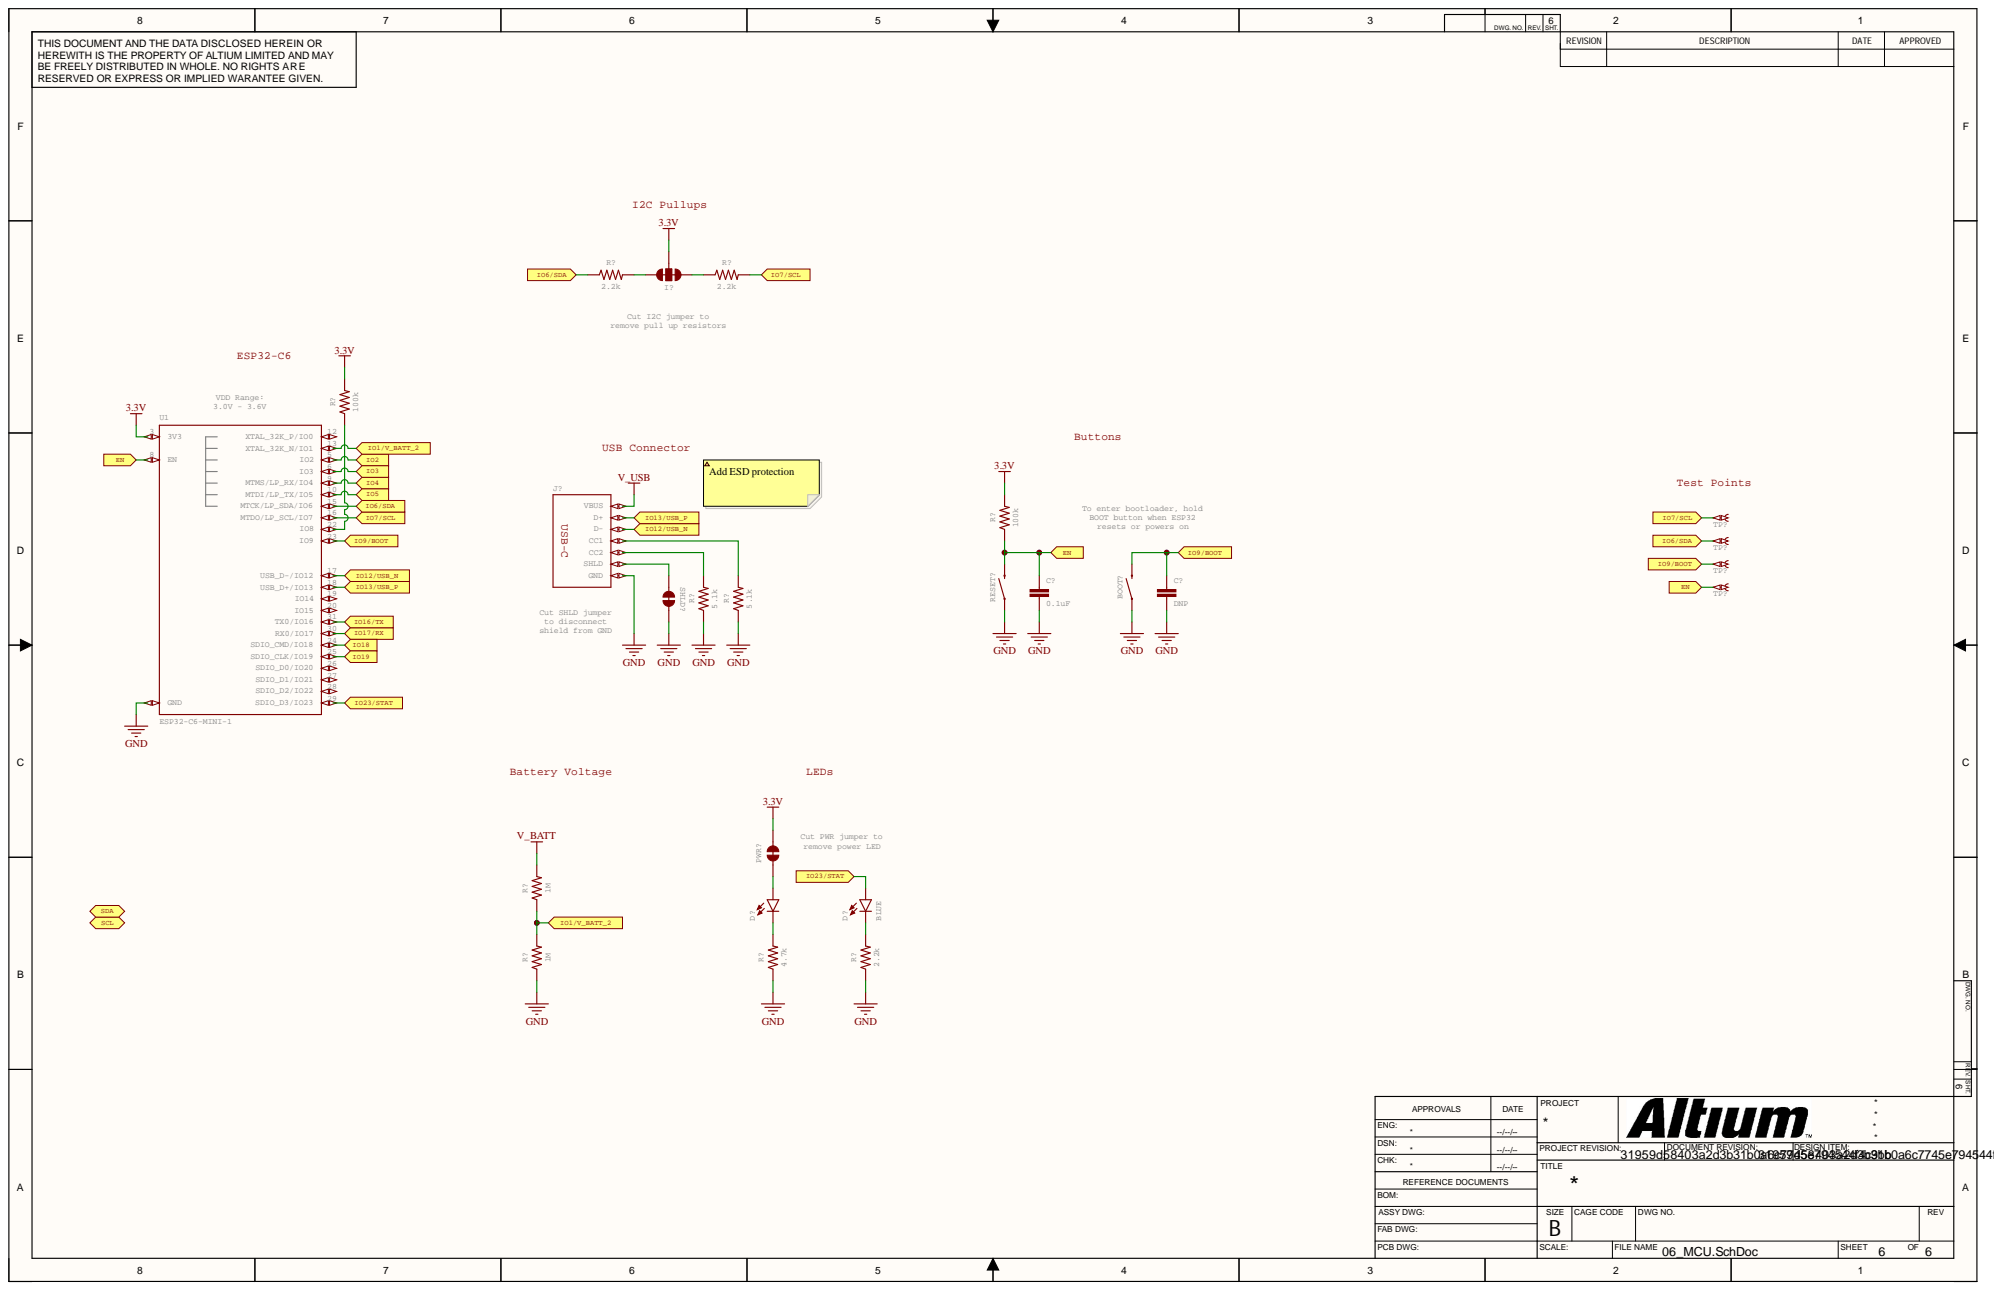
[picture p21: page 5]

THIS DOCUMENT AND THE DA TA DISCLOSED HEREIN OR HEREWITH IS THE PROPERTY OF ALTIUM LIMITED AND MA Y BE FREEL Y DISTRIBUTED IN WHOLE. NO RIGHTS ARE RESERVED OR EXPRESS OR IMPLIED WARANTEE GIVEN. | P u l 3 . 3 V | RE VISIO N | DE SCRIPTIO N | DATE | A P PROV E D

DWG. NO. | RE V. | SHT | .

REV. SHT. DWG. NO.

A P PRO VALS | DATE | PRO J ECT * | ****

ENG : | --/--/--
** DSN: | --/--/--

PRO J ECT RE VISION: 3 1 9 5 9 d | DOCUMENT RE VISION: 5 8 4 0 3 a 2 d 3 b 3 1 b 03a169c57 97 | DE SIGN ITEM: d4 5 e8 74 90435a424df34bc39 1b b 0 a 6 c 7 7 4 5 e | 7

CHK : * | --/--/--

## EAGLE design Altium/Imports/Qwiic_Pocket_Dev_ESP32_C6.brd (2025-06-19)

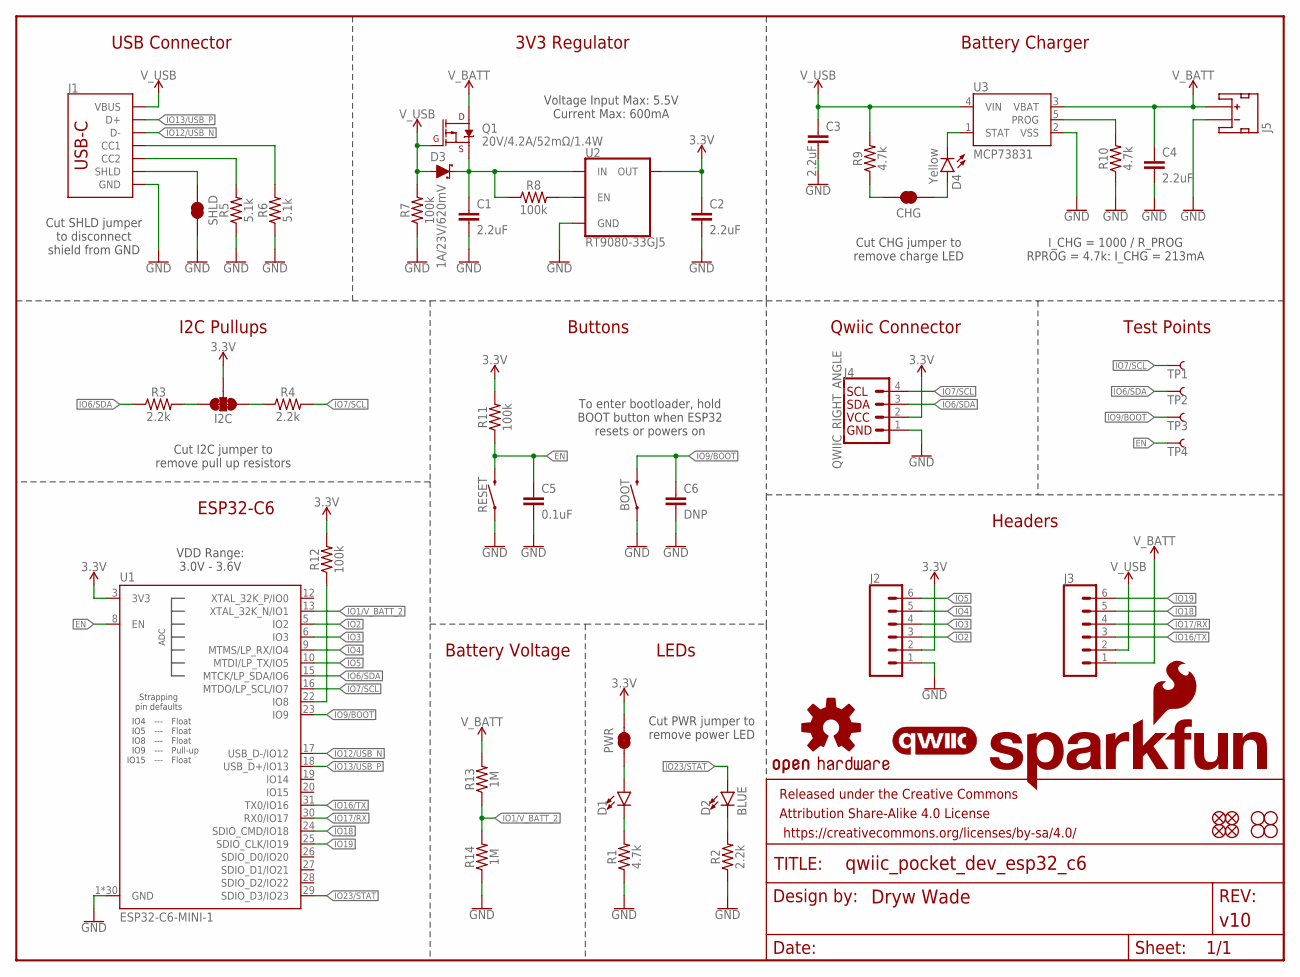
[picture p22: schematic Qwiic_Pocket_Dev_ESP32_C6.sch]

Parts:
BOOT: MOMENTARY-SWITCH-SPST-SMD-4.6X2.8MM; TACTILE_SWITCH_SMD_4.6X2.8MM
C1, C2, C3, C4: 2.2uF; 0402-TIGHT
C5: 0.1uF; 0402-TIGHT
C6: DNP; 0402-TIGHT
CHG: JUMPER-SMT_2_NC_TRACE_SILK; SMT-JUMPER_2_NC_TRACE_SILK
D1: LED-RED_0603-KB; LED-0603
D2: BLUE; LED-0603
D3: 1A/23V/620mV; SOD-323
D4: Yellow; LED-0603
FD1, FD2, FD3, FD4: FIDUCIALUFIDUCIAL; FIDUCIAL-MICRO
FRAME1: FRAME-LETTER; CREATIVE_COMMONS
H1, H2, H3, H4: STAND-OFF
I2C: JUMPER-SMT_3_2-NC_TRACE_SILK; SMT-JUMPER_3_2-NC_TRACE_SILK
J1: USB Female Type C Connector; USB-C-16P_4LAYER-PADS
J2, J3: CONN_06NO_SILK_NO_POP; 1X06_NO_SILK
J4: QWIIC_RIGHT_ANGLE; JST04_1MM_RA
J5: JST_2MM_MALE; JST-2-SMD
LOGO1: SFE_LOGO_NAME_FLAMEBLANK; BLANK
LOGO2: OSHW-LOGOS; OSHW-LOGO-S
LOGO3: QWIIC_LOGO_3MM; QWIIC_3MM
PWR: JUMPER-SMT_2_NC_TRACE_SILK; SMT-JUMPER_2_NC_TRACE_SILK
Q1: 20V/4.2A/52mΩ/1.4W; SOT23-3
R1, R9, R10: 4.7k; 0402-TIGHT
R2, R3, R4: 2.2k; 0402-TIGHT
R5, R6: 5.1k; 0402-TIGHT
R7, R8, R11, R12: 100k; 0402-TIGHT
R13, R14: 1M; 0402-TIGHT
RESET: MOMENTARY-SWITCH-SPST-SMD-4.6X2.8MM; TACTILE_SWITCH_SMD_4.6X2.8MM
SHLD: JUMPER-SMT_2_NC_TRACE_SILK; SMT-JUMPER_2_NC_TRACE_SILK
TP1, TP2, TP3, TP4: TEST-POINT3; PAD.03X.03
U1: ESP32-C6-MINI-1
U2: RT9080-33GJ5; SOT23-5
U3: MCP73831; SOT23-5

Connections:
3.3V: C2.1, I2C.2, J2.2, J4.2, PWR.2, R11.2, R12.2, U1.3 (3V3), U2.5 (OUT)
EN: C5.1, R11.1, RESET.3 (2), RESET.4 (2), TP4.1, U1.8 (EN)
GND: BOOT.1, BOOT.2 (1), C1.2, C2.2, C3.2, C4.2, C5.2, C6.2, J1.GND, J1.GND2 (GND), J2.1, J4.1, J5.1 (-), R1.1, R2.1, R5.1, R6.1, R7.1, R10.1, R14.1, RESET.1, RESET.2 (1), SHLD.2, U1.1 (GND), U1.2 (GND), U1.11 (GND), U1.14 (GND), U1.36 (GND), U1.37 (GND), U1.38 (GND), U1.39 (GND), U1.40 (GND), U1.41 (GND), U1.42 (GND), U1.43 (GND), U1.44 (GND), U1.45 (GND), U1.46 (GND), U1.47 (GND), U1.48 (GND), U1.49.1 (GND), U1.49.2 (GND), U1.49.3 (GND), U1.49.4 (GND), U1.49.5 (GND), U1.49.6 (GND), U1.49.7 (GND), U1.49.8 (GND), U1.49.9 (GND), U1.50 (GND), U1.51 (GND), U1.52 (GND), U1.53 (GND), U2.2 (GND), U3.2 (VSS)
IO1/V_BATT_2: R13.1, R14.2, U1.13 (XTAL_32K_N/IO1)
IO2: J2.3, U1.5 (IO2)
IO3: J2.4, U1.6 (IO3)
IO4: J2.5, U1.9 (MTMS/LP_RX/IO4)
IO5: J2.6, U1.10 (MTDI/LP_TX/IO5)
IO6/SDA: J4.3, R3.1, TP2.1, U1.15 (MTCK/LP_SDA/IO6)
IO7/SCL: J4.4, R4.2, TP1.1, U1.16 (MTDO/LP_SCL/IO7)
IO9/BOOT: BOOT.3 (2), BOOT.4 (2), C6.1, TP3.1, U1.23 (IO9)
IO12/USB_N: J1.A7 (D-), J1.B7 (D-), U1.17 (USB_D-/IO12)
IO13/USB_P: J1.A6 (D+), J1.B6 (D+), U1.18 (USB_D+/IO13)
IO16/TX: J3.3, U1.31 (TX0/IO16)
IO17/RX: J3.4, U1.30 (RX0/IO17)
IO18: J3.5, U1.24 (SDIO_CMD/IO18)
IO19: J3.6, U1.25 (SDIO_CLK/IO19)
IO23/STAT: D2.A, U1.29 (SDIO_D3/IO23)
unnamed: D1.C, R1.2
unnamed: D1.A, PWR.1
unnamed: D2.C, R2.2
unnamed: I2C.3, R3.2
unnamed: I2C.1, R4.1
unnamed: R8.2, U2.3 (EN)
unnamed: J1.B5 (CC2), R5.2
unnamed: J1.A5 (CC1), R6.2
unnamed: C1.1, D3.C, Q1.2 (S), R8.1, U2.1 (IN)
unnamed: D4.C, U3.1 (STAT)
unnamed: CHG.1, D4.A
unnamed: CHG.2, R9.1
unnamed: R10.2, U3.5 (PROG)
unnamed: R12.1, U1.22 (IO8)
SHLD: J1.SHLD1 (SHLD), J1.SHLD2 (SHLD), J1.SHLD3 (SHLD), J1.SHLD4 (SHLD), SHLD.1
V_BATT: C4.1, J3.1, J5.2 (+), Q1.3 (D), R13.2, U3.3 (VBAT)
V_USB: C3.1, D3.A, J1.VBUS1 (VBUS), J1.VBUS2 (VBUS), J3.2, Q1.1 (G), R7.2, R9.2, U3.4 (VIN)

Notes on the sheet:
USB Connector
3V3 Regulator
Battery Charger
Qwiic Connector
Headers
LEDs
Buttons
I2C Pullups
ESP32-C6
VDD Range: 3.0V - 3.6V
Cut I2C jumper to remove pull up resistors
Cut PWR jumper to remove power LED
Cut CHG jumper to remove charge LED
I_CHG = 1000 / R_PROG RPROG = 4.7k: I_CHG = 213mA
Test Points
Voltage Input Max: 5.5V Current Max: 600mA
To enter bootloader, hold BOOT button when ESP32 resets or powers on
Cut SHLD jumper to disconnect shield from GND
Battery Voltage

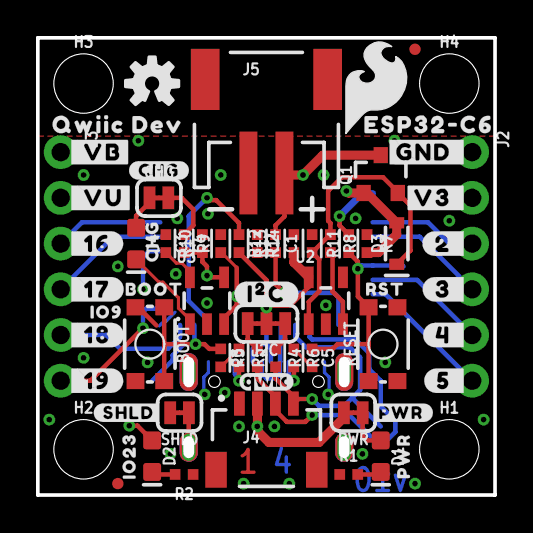
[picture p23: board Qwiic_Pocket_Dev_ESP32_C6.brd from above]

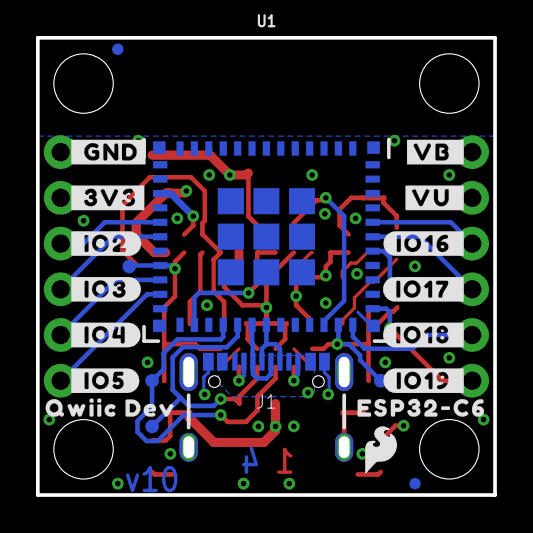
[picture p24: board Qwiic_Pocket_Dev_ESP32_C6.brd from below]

Board: 4 copper layers, 25.4 x 25.4 mm, 96 parts (23 on the bottom side), 35 nets.

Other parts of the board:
U$1: #_GND#0
U$2: #_3V3#0
U$3: #V3_#0
U$5: #GND_#0
U$6: SFE_LOGO_FLAME_.2
U$7: #VU_#0
U$8: #_VB#0
U$9, U$25: QWIIC_DEV0
U$10: SFE_LOGO_FLAME_.1
U$11, U$12: ESP32#C633
U$13: #_IO5#0
U$14: #_IO4#0
U$15: #_IO3#0
U$16: #_IO2#0
U$17: #IO16_#0
U$18: #IO17_#0
U$19: #IO18_#0
U$20: #IO19_#0
U$21: #5_#0
U$22: #4_#0
U$23: #I�C#0
U$24: ORDERING_INSTRUCTIONS
U$26: #PWR#0
U$27: #SHLD#0
U$28: IO230
U$30: PWR0
U$31: #CHG#0
U$32: CHG0
U$33: BOOT0
U$34: RST0
U$35: IO90
U$36: #VB_#0
U$37: #_VU#0
U$38: #3_#0
U$39: #2_#0
U$40: #_16#0
U$41: #_17#0
U$42: #_18#0
U$43: #_19#0

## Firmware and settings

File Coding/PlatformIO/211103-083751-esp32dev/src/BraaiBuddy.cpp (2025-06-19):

//  includes
#include <Arduino.h>
#include <EEPROM.h>
#include <ESPAsyncWebServer.h>
#include <FS.h>
#include <HTTPClient.h>
#include <OneWire.h>
#include <SPIFFS.h>

#include <SPI.h>
#include <WebSocketsServer.h>
#include <WiFi.h>
#include <esp_task_wdt.h>

#include "Adafruit_MCP9600.h"
#include "LIS3DHTR.h"

// header files
#include "Globals.h"
#include "LocalOTA.h"
#include "time.h"

// SD card includes
#include <SD.h>
SPIClass SD_SPI(FSPI);
#define SD_CLK 19              // SD card clock pin
#define SD_MISO 20             // SD card MISO pin
#define SD_MOSI 18             // SD card MOSI pin
#define SD_CS 23               // SD card CS pin
#define SD_DETECT_PIN 5        // GPIO5 for SD card detect
bool last_sd_inserted = false; // Track previous state

LIS3DHTR<TwoWire> LIS; // IIC

// Define I2C pins
#define WIRE Wire
#define IIC_SDA 6 // SDA on GPIO6
#define IIC_SCL 7 // SCL on GPIO7

// I2C Addresses (MCP9600's):
#define I2C_ADDRESS_1 (0x60) // CONN1
#define I2C_ADDRESS_2 (0x62) // CONN2
#define I2C_ADDRESS_3 (0x64) // CONN3
#define I2C_ADDRESS_4 (0x66) // CONN4
#define I2C_ADDRESS_5 (0x67) // CONN5

// I2C Address (LIS3DH):
#define ACC_I2C_ADR 0x18

Adafruit_MCP9600 mcp1;
Adafruit_MCP9600 mcp2;
Adafruit_MCP9600 mcp3;
Adafruit_MCP9600 mcp4;
Adafruit_MCP9600 mcp5;

// RGB pin setup
#define LED_RED_PIN 3
#define LED_GREEN_PIN 2
#define LED_BLUE_PIN 4

// Buzzer pin Setup
#define BUZZER_PIN 14

// Battery voltage divider pin
#define BATTERY_ADC_PIN 1 // ADC1 on GPIO1

// Buzzer notes
#define NOTE_C4 262
#define NOTE_CS4 277
#define NOTE_D4 294
#define NOTE_DS4 311
#define NOTE_E4 330
#define NOTE_F4 349
#define NOTE_FS4 370
#define NOTE_G4 392
#define NOTE_GS4 415
#define NOTE_A4 440
#define NOTE_AS4 466
#define NOTE_B4 494

// IP Address RGB LED handling
bool IP_address_sequence_done = false;
enum IP_address_sequence_state
{
    IP_IDLE,
    IP_NEXT_CHAR,
    IP_SET_COLOR,
    IP_BEEP_ON,
    IP_BEEP_OFF,
    IP_DOT_PAUSE,
    IP_CHAR_PAUSE,
    IP_DONE
};
static IP_address_sequence_state ip_comm_state = IP_IDLE;
static unsigned long ip_comm_timer = 0;
static int ip_comm_index = 0;
static int ip_comm_beep_count = 0;
static int ip_comm_beep_target = 0;
static int ip_comm_color_phase = 0; // 0=red, 1=green, 2=blue

// Grid Turn Time variables
int grid_turn_time = 180; // in seconds

// SD card variables
// bool csv_labels_written = false;

// Stuct setup
struct SensorData sensor_data;
struct SystemStatus system_status;
struct WebSystemState web_system_state;

/* Set and print ambient resolution */
Ambient_Resolution ambientRes = RES_ZERO_POINT_0625;

//  Wifi Constants
const char *password = "braaibuddy";
const int dns_port = 53;
const int http_port = 80;
const int ws_port = 1337;

uint8_t start_ap = 1; // 1 for True then start wifi AP
char ssid_buffer[19];
String ip_address;
char network_password[64] = ""; // Max password length is 64 characters
// char network_password[64] = "salamander";
uint8_t raw_data[512];

// Webserver and sockets
AsyncWebServer server(80);
WebSocketsServer web_socket = WebSocketsServer(1337);
char msg_buf[255];
// char network_ssid[32] = "Estiaan PC";
char network_ssid[32] = ""; // Max SSID length is 32 characters

// defines
#define TRUE 1
#define FALSE 0
#define WDT_TIMEOUT 10 // seconds
#define EEPROM_SIZE 512

// Timer flags
hw_timer_t *task_timer = NULL;
uint32_t timer_1_ms = 0;
uint8_t do_1_hz_task = 0;
uint8_t do_100hz_task = 0;
uint8_t do_2s_task = 0;
uint8_t do_20hz_task = 0;
uint8_t do_initialise_web_service = 0;
uint8_t do_ota_update = 0;

// Sequence selection flags
char CH1_seq[20];
char CH2_seq[20];
char CH3_seq[20];
char CH4_seq[20];
char CH5_seq[20];
bool CH1_seq_active = false;
bool CH2_seq_active = false;
bool CH3_seq_active = false;
bool CH4_seq_active = false;
bool CH5_seq_active = false;

// Array
volatile float temp_readings[18000] = {0}; // 18000 = 5 hours of data at 1Hz

// Function declarations
void wifi_event(WiFiEvent_t event);
void initialise_web_services(void);
void on_web_socket_event(uint8_t client_num, WStype_t type, uint8_t *payload, size_t length);
void on_index_request(AsyncWebServerRequest *request);
void on_network_connect_request(AsyncWebServerRequest *request);
void on_css_request(AsyncWebServerRequest *request);
void on_page_not_found(AsyncWebServerRequest *request);
void led_rgb_setup(void);
void led_rgb_handling(void);
void accelerometer_setup(void);
void accelerometer_handling(void);
void temp_sensors_setup(void);
void temp_sensor_handling(void);
void buzzer_handling(void);
void sequence_handling(void);
void sequence_handling_data_capture(void);
void refresh_handling(void);
void ip_address_start_sequence(void); // Start IP address RGB+Buzzer sequence
void ip_address_handling(void);
void set_rgb_color(uint8_t r, uint8_t g, uint8_t b);
void clear_temperature_log_file(void);
void log_temperature_to_sd_card(float temp1, float temp2, float temp3, float temp4, float temp5);
void read_battery_voltage(void);
void log_sequence_completion_to_sd(int probe_num, const char *test_type, float temp);
void data_retrieval_test_handling(void);

// Timers acting as task schedulers
void IRAM_ATTR onTimer()
{
    timer_1_ms++;
    // Serial.println("Timer 1ms ticked");
    if ((timer_1_ms % 1000) == 0)
    {
        do_1_hz_task = TRUE;
    }
    if ((timer_1_ms % 100) == 0)
    {
        do_100hz_task = TRUE; // 100Hz task flag
    }
    if ((timer_1_ms % 50) == 0)
    {
        do_20hz_task = TRUE;
    }
    if ((timer_1_ms % 2000) == 0)
    {
        do_2s_task = TRUE;
    }
    if (timer_1_ms > 0xFFFFFFFE)
    { // reset timer_1_ms to prevent overflow
        timer_1_ms = 0;
    }
}

void setup()
{
    // Start Serial port for debugging
    Serial.begin(115200);

    // Sequence handling flag
    web_system_state.sequence_active = false;

    // RGB LED pin setup
    led_rgb_setup();

    // Set I2C pins
    Wire.begin(IIC_SDA, IIC_SCL); // SDA, SCL

    // Temperature sensor setup
    temp_sensors_setup();

    // Accelerometer setup
    accelerometer_setup();

    // Buzzer pin setup
    pinMode(BUZZER_PIN, OUTPUT);

    // SD card detect pin setup
    pinMode(SD_DETECT_PIN, INPUT_PULLUP); // SD detect pin, HIGH = no card, LOW = card inserted
    last_sd_inserted = (digitalRead(SD_DETECT_PIN) == LOW);

    // Initialize SD card in SPI mode (4-bit mode not supported with ESP32-C6)
    // Custom SPI pins for SD card
    SD_SPI.begin(SD_CLK, SD_MISO, SD_MOSI, SD_CS);
    if (!SD.begin(SD_CS, SD_SPI))
    {
        Serial.println("SD Card Mount Failed!");
    }
    else
    {
        Serial.println("SD Card initialized in SPI mode.");
        clear_temperature_log_file(); // Clear the temperature log file on startup
    }

    // create unique wifi ssid from ESP32 chip ID
    uint64_t chip_id;
    char chip_id_string_array[30];
    chip_id = ESP.getEfuseMac();
    char id_lower_4_bytes[9];
    char id_higher_2_bytes[5];
    id_lower_4_bytes[8] = '\0';
    id_higher_2_bytes[4] = '\0';
    sprintf(id_lower_4_bytes, "%08X", (uint32_t)chip_id);
    sprintf(id_higher_2_bytes, "%04X", (uint16_t)(chip_id >> 32));
    sprintf(chip_id_string_array, "%s%s", id_higher_2_bytes, id_lower_4_bytes);
    chip_id_string_array[12] = '\0';
    sprintf(ssid_buffer, "BB1 %s", chip_id_string_array);
    Serial.println(ssid_buffer);

    // Make sure we can read the file system, if not, let watchdog reset the ESP32
    if (!SPIFFS.begin())
    {
        Serial.println("Error mounting SPIFFS");
        while (1)
            ;
    }

    EEPROM.begin(EEPROM_SIZE); // EEPROM has a maximum of 512 bytes in flash
                               /*EEPROM memory map
                                *Byte 0-30 SSID
                                *Byte 31-60 Password
                                */

    if (network_ssid[0] == 0)
    {
        start_ap = TRUE;
    }
    else if (network_ssid[0] == 255)
    {
        Serial.println("Firmware was updated via USB, clearing network credentials ");
        start_ap = TRUE;
        for (uint8_t network_clear_counter = 1; network_clear_counter < 61; network_clear_counter++)
        {
            EEPROM.write(network_clear_counter, 0); // Clear saved network credentials
            EEPROM.commit();
        }
        EEPROM.write(61, 0); // Clear saved network credentials
        EEPROM.commit();
    }
    else
    {
        start_ap = FALSE;
    }

    //  Start listening for Wifi events
    WiFi.onEvent(wifi_event);

    // // Timers
    task_timer = timerBegin(1000000);
    timerAttachInterrupt(task_timer, &onTimer);
    timerWrite(task_timer, 1000);                           // Set to 1000000 for a sec and decrease for faster
    timerAlarm(task_timer, 1000, true, (sizeof(uint64_t))); // Set alarm to 1 second (1000000 microseconds) and auto-reload
    timerStart(task_timer);                                 // Start the timer

    // Starting WiFi AP and connecting to local network
    WiFi.mode(WIFI_AP_STA);
    WiFi.softAP(ssid_buffer, password);

    // If no network credentials are found
    if (start_ap == TRUE)
    {
        Serial.println("AP running");
        Serial.print("AP IP address: ");
        Serial.println(WiFi.softAPIP()); // Print our IP address
        ip_address = WiFi.softAPIP().toString();
    }
    else
    {
        WiFi.begin(network_ssid, network_password);
        Serial.println("Connecting to local network : ");
        Serial.println(network_ssid);
        Serial.println(network_password);
    }

    // initialize watchdog timers at end of setup()
    esp_task_wdt_config_t wdt_config = {
        .timeout_ms = WDT_TIMEOUT * 1000, // Convert seconds to milliseconds
        .trigger_panic = true             // Enable panic so ESP32 restarts
    };
    esp_task_wdt_init(&wdt_config); // Initialize watchdog with the new configuration
    esp_task_wdt_add(NULL);         // add main thread to WDT watch list
}
/////////////////////////////////////////////////////////////////////////////////////////MAIN////////////////////////////////////////////////////////////////////////////////////////////
void loop()
{                         // main loop
    esp_task_wdt_reset(); // kick watchdog

    if (do_initialise_web_service == TRUE)
    {
        do_initialise_web_service = FALSE;
        initialise_web_services(); // start websockets etc after establishing wifi connection
        Serial.println("Web services initialised");
    }

    if (!do_initialise_web_service)
    {
        web_socket.loop(); // Look for and handle WebSocket data asynchronously
    }

    // if (do_ota_update) // if OTA update is requested, disable timer and start OTA process
    // {
    //     do_ota_update = 0;
    //     // timerAlarmDisable(task_timer);
    //     timerDetachInterrupt(task_timer);
    //     init_local_ota();
    //     local_ota_loop();
    // }

    if (do_20hz_task) // 20Hz task
    {
        do_20hz_task = FALSE;
        // Serial.println("[20Hz] 20Hz task triggered");

        // 20Hz tasks go here
        accelerometer_handling();

        // if (web_system_state.webpage_load_graph_info == true)
        // {
        //     refresh_handling();
        // }
    }

    if (do_1_hz_task) // 1Hz task
    {
        do_1_hz_task = FALSE;
        // Serial.println("[1Hz] 1Hz task triggered");

        // 1Hz tasks go here
        temp_sensor_handling();
        // led_rgb_handling();

        // Sequence handling
        if (web_system_state.sequence_active == true)
        {
            sequence_handling();
            sequence_handling_data_capture(); // Capture data for the sequence
        }

        // Data retrieval test
        // data_retrieval_test_handling(); // Handle data retrieval test

        // SD card detect handling
        bool sd_inserted = (digitalRead(SD_DETECT_PIN) == LOW);
        if (sd_inserted != last_sd_inserted)
        {
            if (sd_inserted)
            {
                Serial.println("SD card inserted.");
            }
            else
            {
                Serial.println("SD card removed.");
            }
            last_sd_inserted = sd_inserted;
        }
        // Always print current state at 1Hz
        Serial.print("SD card state: ");
        Serial.println(sd_inserted ? "Inserted" : "Not inserted");
    }

    if (do_100hz_task) // 100Hz task
    {
        do_100hz_task = FALSE;
        // Serial.println("[100Hz] 100Hz task triggered");

        ip_address_handling(); // IP address sequence handling
    }

    if (do_2s_task) // 2s task
    {
        do_2s_task = FALSE;
        // Serial.println("[0.5Hz] 0.5Hz task triggered");

        // 2s tasks go here
        read_battery_voltage();
    }
}

int8_t wifi_network_scan() // returns number of networks found
{
    Serial.println("Wi-Fi network scan start");
    int8_t n = WiFi.scanNetworks(); // WiFi.scanNetworks will return the number of networks found
    Serial.println("scan done");
    if (n <= 0)
    {
        Serial.println("no networks found");
    }
    else
    {
        Serial.print(n);
        Serial.println(" networks found");
        for (uint8_t i = 0; i < n; ++i) // Print SSID and RSSI for each network found
        {
            Serial.print(i + 1);
            Serial.print(": ");
            Serial.print(WiFi.SSID(i));
        }
    }
    Serial.println("");
    return (n);
}

void recover_wifi_connection() // attempt to reconnect to stored network
{
    if ((WiFi.status() != WL_CONNECTED) && (start_ap == FALSE))
    {
        uint8_t MatchingNetworkFound = FALSE;
        Serial.println("Wifi disconnected, attempting to reconnect now");
        WiFi.disconnect(true);
        int8_t n = wifi_network_scan();
        if (n < 0)
        {
            n = 0;
        }
        for (int8_t i = 0; i < n; ++i)
        {
            char temp[4];
            WiFi.SSID(i).toCharArray(temp, sizeof(temp));
            if (temp[0] == network_ssid[0])
                if (temp[1] == network_ssid[1])
                    if (temp[2] == network_ssid[2])
                    {
                        i = n;
                        Serial.println(
                            "Network found that matched stored credentials, "
                            "attempting connection now");
                        WiFi.disconnect();
                        WiFi.begin(network_ssid, network_password);
                        Serial.println("Connecting to local network : ");
                        Serial.println(network_ssid);
                        Serial.println(network_password);
                        MatchingNetworkFound = TRUE;
                    }
        }
        if (MatchingNetworkFound == FALSE)
        {
            Serial.println("No matching networks found, starting AP");
            WiFi.disconnect();
            Serial.println("AP running");
            Serial.print("My IP address: "); // Print our IP address
            Serial.println(WiFi.softAPIP());
            ip_address = WiFi.softAPIP().toString();
        }
    }
}

void wifi_event(WiFiEvent_t event)
{
    Serial.printf("[WiFi-event] event: %d\n", event);
    switch (event)
    {
    case ARDUINO_EVENT_WIFI_READY:
        Serial.println("WiFi interface ready");
        break;
    case ARDUINO_EVENT_WIFI_SCAN_DONE:
        Serial.println("Completed scan for access points");
        break;
    case ARDUINO_EVENT_WIFI_STA_START:
        Serial.println("WiFi client started");
        break;
    case ARDUINO_EVENT_WIFI_STA_STOP:
        Serial.println("WiFi clients stopped");
        break;
    case ARDUINO_EVENT_WIFI_STA_CONNECTED:
        Serial.println("Connected to access point");
        break;
    case ARDUINO_EVENT_WIFI_STA_DISCONNECTED:
        Serial.println("Disconnected from WiFi access point or connection failed");
        if (start_ap == FALSE)
        {
            Serial.println("Lost connection to AP, reconnecting...");
        }
        break;
    case ARDUINO_EVENT_WIFI_STA_AUTHMODE_CHANGE:
        Serial.println("Authentication mode of access point has changed");
        break;
    case ARDUINO_EVENT_WIFI_STA_GOT_IP:
        Serial.print("Obtained IP address: ");
        Serial.println(WiFi.localIP());
        Serial.println("Connected to local network:");
        Serial.println(network_ssid);
        Serial.print("My IP address: ");
        Serial.println(WiFi.localIP());
        ip_address = WiFi.localIP().toString();
        do_initialise_web_service = TRUE;
        Serial.println("Initialise web services flag set to TRUE");
        ip_address_start_sequence(); // Start IP address RGB+Buzzer sequence
        break;
    case ARDUINO_EVENT_WIFI_STA_LOST_IP:
        Serial.println("Lost IP address and IP address is reset to 0");
        break;
    case ARDUINO_EVENT_WIFI_AP_START:
        Serial.println("WiFi access point started");
        Serial.println("AP running");
        Serial.print("My IP address: ");
        Serial.println(WiFi.softAPIP());
        ip_address = WiFi.softAPIP().toString();
        do_initialise_web_service = TRUE;
        Serial.println("Initialise web services flag set to TRUE (1)");
        ip_address_start_sequence(); // Start IP address RGB+Buzzer sequence
        break;
    case ARDUINO_EVENT_WIFI_AP_STOP:
        Serial.println("WiFi access point  stopped");
        break;
    case ARDUINO_EVENT_WIFI_AP_STACONNECTED:
        Serial.println("Client connected");
        break;
    case ARDUINO_EVENT_WIFI_AP_STADISCONNECTED:
        Serial.println("Client disconnected");
        break;
    case ARDUINO_EVENT_WIFI_AP_STAIPASSIGNED:
        Serial.println("Assigned IP address to client");
        Serial.println(WiFi.softAPIP());
        break;
    case ARDUINO_EVENT_WIFI_AP_PROBEREQRECVED:
        Serial.println("Received probe request");
        break;
    default:
        break;
    }
}

void initialise_web_services()
{
    web_socket.begin(); // Start WebSocket server and assign callback when
                        // connected to WiFi network
    web_socket.onEvent(on_web_socket_event);
    server.begin(); // Start web server
    server.on("/", HTTP_GET,
              on_index_request); // On HTTP request for root, provide index.html file
    server.on("/NetworkConnection", HTTP_GET,
              on_network_connect_request); // On HTTP request for connect to local network
    server.on("/style.css", HTTP_GET,
              on_css_request); // On HTTP request for style sheet, provide style.css

    server.on("/chart.js", HTTP_GET, [](AsyncWebServerRequest *request)
              { request->send(SPIFFS, "/chart.js", "application/javascript"); }); // Serve chart.js file
    server.on("/chartjs-adapter-date-fns.js", HTTP_GET, [](AsyncWebServerRequest *request)
              { request->send(SPIFFS, "/chartjs-adapter-date-fns.js", "application/javascript"); }); // Serve chartjs-adapter-date-fns.js file

    server.onNotFound(on_page_not_found); // Handle requests for pages that do not exist
}
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

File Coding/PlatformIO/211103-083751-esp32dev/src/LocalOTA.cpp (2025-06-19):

#include "LocalOTA.h"
#include <ESPAsyncWebServer.h>
#include <ESPmDNS.h>
#include <SPIFFS.h>
#include <Update.h>
#include <esp_task_wdt.h>
#define U_PART U_SPIFFS

size_t content_len;
AsyncWebServer OTAserver(100);

void handleRoot(AsyncWebServerRequest *request)
{
    request->redirect("/update");
}

void handleUpdate(AsyncWebServerRequest *request)
{
    request->send(SPIFFS, "/OTA.html", "text/html");
}

void handleDoUpdate(AsyncWebServerRequest *request, const String &filename, size_t index, uint8_t *data, size_t len, bool final)
{
    if (!index)
    {
        Serial.println("Update");
        content_len = request->contentLength();
        // if filename includes spiffs, update the spiffs partition
        int cmd = (filename.indexOf("SPIFFS") > -1) ? U_PART : U_FLASH;
        int FWpos = filename.indexOf("FW");
        Serial.print("CMD value: ");
        Serial.println(cmd);
        Serial.print("FWPos value: ");
        Serial.println(FWpos);
        if ((cmd != 100) & (FWpos != 10))
        {
            Serial.println("Incorrect file for update, restarting...");
            request->send(200, "text/plain", "Incorrect file for upload, restarting ...");
            delay(3000);
            ESP.restart();
        }
#ifdef ESP8266
        Update.runAsync(true);
        if (!Update.begin(content_len, cmd))
        {
#else
        if (!Update.begin(UPDATE_SIZE_UNKNOWN, cmd))
        {
#endif
            Update.printError(Serial);
        }
    }

    if (Update.write(data, len) != len)
    {
        Update.printError(Serial);
#ifdef ESP8266
    }
    else
    {
        Serial.printf("Progress: %d%%\n", (Update.progress() * 100) / Update.size());
#endif
    }

    if (final)
    {
        if (!Update.end(true))
        {
            Update.printError(Serial);
        }
        else
        {
            Serial.println("Update complete");
            request->send(200, "text/plain", "Update completed sucessfully, restarting now...");
            delay(5000);
            Serial.flush();
            ESP.restart();
        }
    }
}

void printProgress(size_t prg, size_t sz)
{
    Serial.printf("Progress: %d%%\n", (prg * 100) / content_len);
}

void init_local_ota()
{
    esp_task_wdt_deinit();
    OTAserver.on("/", HTTP_GET, [](AsyncWebServerRequest *request)
                 { request->redirect("/update"); });
    OTAserver.on("/update", HTTP_GET, [](AsyncWebServerRequest *request)
                 { handleUpdate(request); });
    OTAserver.on("/doUpdate", HTTP_POST, [](AsyncWebServerRequest *request) {}, [](AsyncWebServerRequest *request, const String &filename, size_t index, uint8_t *data, size_t len, bool final)
                 { handleDoUpdate(request, filename, index, data, len, final); });
    OTAserver.onNotFound([](AsyncWebServerRequest *request)
                         { request->send(404); });
    OTAserver.begin();
#ifdef ESP32
    Update.onProgress(printProgress);
#endif
    MDNS.addService("http", "tcp", 100);
}

void local_ota_loop()
{
    while (1)
    {
        delay(5);
        esp_task_wdt_reset();
    }
}

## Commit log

2025-06-19 First upload of all files
    [01_Top.SchDoc, 02_Power.SchDoc, 03_Temp_Sensor.SchDoc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]
2026-11-08 Restructure repo and rewrite README
    - New README with photo, specs, block diagram, design decisions,
    verification and roadmap
    - Move PlatformIO project to Firmware/ and bring-up sketches to
    Firmware/bring-up-tests/
    - Move PCB photo to docs/images/, purchasing files into the BOM folder
    - Remove duplicate report PDF
    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

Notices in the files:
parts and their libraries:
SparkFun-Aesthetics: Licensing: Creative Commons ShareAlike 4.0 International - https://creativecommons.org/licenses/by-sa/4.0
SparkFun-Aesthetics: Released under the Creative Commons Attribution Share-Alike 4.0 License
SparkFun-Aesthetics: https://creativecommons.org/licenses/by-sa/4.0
